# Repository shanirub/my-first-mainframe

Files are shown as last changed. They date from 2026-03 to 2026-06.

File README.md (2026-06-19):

# 🖥️ Low-Level Mainframe Simulation Using MCUs

> Simulating a banking mainframe architecture using four ESP32-C3 microcontrollers and a
> Raspberry Pi 3B+ — because understanding distributed systems is way more fun when you
> can hold the hardware in your hands.

---

## 🪦 Project status: RETIRED — frozen at ADR-012 (2026-06-18)

**This repository is closed.** The shared-I2C-bus architecture it was built around
(ADR-008 → ADR-011) has been retired *in full* by the terminal decision record
[ADR-012](docs/decisions/ADR-012-retire-shared-bus-begin-mainframe-core-redesign.md).
Work continues in a **successor project** with a different inter-device transport and a
re-centred architecture (see [Why it was retired](#-why-it-was-retired) and
[The successor](#-the-successor) below).

Nothing here is deleted. The firmware, the libraries, and the BSC slave code are preserved
as the **investigation record** — the reasoning that led to the redesign is the point of
keeping them.

| | |
|---|---|
| **Terminal ADR** | ADR-012 — *Retire the shared-bus subsystem architecture; begin mainframe-core redesign* |
| **Retired** | The shared I2C inter-device bus, the "co-equal subsystems on one bus" premise, the RPi BSC slave |
| **Still in use** | I2C for the *private* per-device OLED displays only |
| **Carried forward** | Subsystem decomposition, message semantics, FreeRTOS task pattern, SQLite/WAL durability plan, all physical hardware |

---

## 📖 What this project was

A low-level simulation of a banking mainframe built from four ESP32-C3 microcontrollers and
a Raspberry Pi 3B+, each device mapped to a distinct mainframe subsystem. The devices
communicated over a **shared I2C bus** — a single two-wire bus (SDA/SCL) shared by all
devices — chosen to mirror the channel-subsystem architecture of IBM z/OS mainframes.

Each subsystem ran autonomously and coordinated with its peers to process banking
transactions (deposits, withdrawals, transfers, balance queries). The build was
deliberately low-level: no frameworks or abstractions beyond what the project built itself,
with every design decision documented in the devlog and the ADRs (Architecture Decision
Records — short documents that capture *what* was decided and *why*).

The project was educational in intent but rigorous in execution. Real hardware constraints
were discovered through testing and resolved through principled architectural decisions —
and ultimately one of those decisions was to **stop**, which is what ADR-012 records.

---

## 🧭 Why it was retired

The retirement was an *architectural* decision, not a workaround. The recurring failures
were diagnosed as a **wrong-bus-for-the-role mismatch**, and the correct response was judged
to be changing the architecture that forced those roles — not patching the wire beneath it
again.

### The structural mismatch

I2C is a primary/secondary (historically "master/slave") bus: well suited to one controller
talking to simple peripherals. This project pressed it into **two roles it suits poorly**:

1. **Multi-master peer messaging with runtime mode-switching** — devices flipping between
   controller and target roles at runtime to form a heartbeat/ACK mesh. Documented as very
   difficult to stabilise.
2. **Target ("slave") mode on devices with weak target support** — the ESP32 I2C-slave
   initialisation path (watchdog resets, `TG1WDT_SYS_RESET`, inside untested IDF driver
   paths) and the Linux/BSC slave on the Raspberry Pi.

This was the **fourth manifestation of one underlying mismatch**. ADR-008 (SD card → three
board swaps), ADR-009 (UART backend), ADR-010 (switch to pure ESP-IDF), and ADR-011 (RPi as
BSC slave) were each well-reasoned escapes from the *same* trap — and each **moved** the
failure rather than removing it. Continuing to patch the transport was continuing to fight
the bus.

### The immediate trigger (Phase 3.3) — stated with calibrated confidence

The proximate cause surfaced at Phase 3.3: the **BCM2837 BSC** (Broadcom Serial Controller)
slave peripheral that `pigpio bsc_i2c()` drives has a **16-byte hardware FIFO** (a small
first-in-first-out buffer in silicon), which conflicts with the 256-byte fixed-buffer TX
protocol the design assumed.

Two distinct questions came out of investigating the `pigpio` source (`bscXfer()` in
`pigpio.c`), and they resolved differently:

- **Message size — closed.** The 16-byte FIFO is *not* a hard message-size limit. `pigpio`
  drains it in a software busy-loop into a 512-byte buffer while the transaction is active,
  so a chunking protocol is not *strictly* forced.
- **Reliability — not closed.** The servicing is **PIO** (programmed I/O — the CPU
  hand-copies each byte) with **no DMA** (no direct-memory-access engine to move bytes
  without the CPU). A message larger than 16 bytes at 400 kHz arrives intact only if the
  daemon is already servicing the FIFO *during* the transaction; the 16-byte slack overruns
  in roughly **360 µs**. Reliable reception is therefore a **timing gamble on a loaded Linux
  host**, not a guarantee.

The reliability question was judged **not worth resolving empirically**, because the
structural mismatch above made the whole transport the wrong foundation regardless of the
outcome of one timing test.

> *Note on a cross-reference:* the previous README attributed the MCU #3 / ESP32 I2C-slave
> retirement to ADR-011. ADR-012's own account maps the ESP32 slave-init watchdog issue to
> **ADR-010** and ADR-011 to the **RPi-as-BSC-slave** decision. This README follows ADR-012
> as the authoritative consolidating record; the exact inner ADR numbering can be reconciled
> against ADR-008–011 directly.

---

## 🚀 The successor

A new project replaces this one. ADR-012 deliberately does **not** elaborate the successor's
design — *it will have its own ADR-001 and design documents* — so only the committed
direction is recorded here (anything beyond this would be speculation):

- The **Raspberry Pi becomes the mainframe central complex**: the CICS-analogue
  (transaction monitor), the transaction processor, and the job scheduler run on the Pi as
  **software subsystems**, and durable storage (SQLite) is **local to the Pi**.
- The four **ESP32-C3 MCUs become channel-attached peripherals** — operator console,
  terminals, I/O channels — rather than co-equal bus subsystems.
- The **inter-device transport is reselected** from a bus suited to the role (the specific
  choice belongs to the successor's docs, not here).

---

## 📦 What carries forward

The transport was the failure; the system above it was not. These are sound and migrate to
the successor as concepts:

- The **subsystem decomposition** and the **CICS-minimal transaction flow**
  (deposit / withdraw / balance → durable storage → acknowledge).
- The **message semantics**: `HEARTBEAT`/`ACK`, `DB_READ`/`DB_WRITE`, job
  submit/dispatch/complete.
- The **FreeRTOS task pattern** on the MCUs and the **SQLite/WAL** (write-ahead logging — a
  journaling mode that lets storage survive a mid-write crash) durability plan.
- **All physical hardware**: the 4 ESP32-C3 MCUs, the RPi 3B+, the 5 OLEDs, the power
  arrangement, the breadboards, and the logic analyzer.

The functional goal is unchanged: a minimal CICS analogue with durable, reboot-surviving
storage. Only the architecture that delivers it changes.

---

## 🏛️ Architecture as built (historical record)

> Everything below documents the **retired** shared-bus design as it stood when the project
> was frozen. It is kept for reference, not as a description of current or future work.

Four ESP32-C3 microcontrollers and one Raspberry Pi 3B+, each mapped to a real mainframe
subsystem:

| MCU | Role | Mainframe Equivalent | I2C Address |
|-----|---|---|---|
| #1 | Master Console | System Console / Operator Interface | `0x08` |
| #2 | Transaction Processor | Central Processor (CP) | `0x09` |
| RPi 3B+ | Database Controller | DASD Controller | `0x0A` |
| #4 | Job Scheduler | JES (Job Entry Subsystem) | `0x0B` |
| #5 | I/O Controller | Channel Subsystem | `0x0C` |

> MCU #3 (ESP32-WROOM-32 DevKit) was retired across the ADR-008/011 line after an I2C
> slave-initialisation failure on the ESP32 platform (`i2c_new_slave_device()` triggering an
> unrecoverable watchdog reset; Espressif does not officially validate that slave driver path
> on the plain ESP32). The Raspberry Pi 3B+ replaced it directly at the same bus address.
> The entire shared-bus Database Controller role is itself now retired by ADR-012.

All devices shared a single I2C bus (400 kHz) and communicated via JSON-encoded messages
with a strict schema. Each device had its own OLED display showing real-time subsystem
state.

### Per-device bus architecture

Each ESP32-C3 MCU ran two independent I2C buses:
- **Shared bus (GPIO8/GPIO9):** inter-device communication via hardware `TwoWire(0)`.
- **Private OLED bus (GPIO3/GPIO10):** local display via U8g2 software I2C.

The ESP32-C3 has only one hardware I2C peripheral. That constraint was discovered during
development and resolved with U8g2 software I2C (bit-banged I2C in software on arbitrary
GPIO pins) — documented in ADR-002. **This OLED split is the one part of the I2C design that
survives the retirement.**

The Raspberry Pi 3B+ used a different mechanism for the same split:
- **Shared bus (GPIO18/GPIO19):** BCM2837 BSC slave peripheral — hardware-backed I2C slave,
  controlled via `pigpio bsc_i2c()`. GPIO18/19 are hardwired to this peripheral in silicon
  and cannot be reassigned. **(Retired by ADR-012 — see [Why it was retired](#-why-it-was-retired).)**
- **Private OLED (GPIO2/GPIO3):** BCM2837 BSC1 master peripheral via `luma.oled`. Separate
  hardware from the shared bus — no interference.

The RPi operated as a **pure I2C slave** on the shared bus: it never initiated a
transmission, and responses were returned via master-read (the requesting MCU stayed master
for the full exchange and clocked the response out of the RPi's TX FIFO). This is exactly
the path the 16-byte BSC FIFO undermined.

### FreeRTOS task architecture (MCUs) — *carries forward*

Each ESP32-C3 MCU ran a set of FreeRTOS tasks rather than a single Arduino `loop()`. Tasks
communicated via queues and shared resources via mutexes (mutual-exclusion locks). This was
a mid-project pivot (Phase 2.5) driven by a hardware constraint: `TwoWire` cannot switch
between master and slave mode at runtime without FreeRTOS managing the transition (ADR-007).

Each MCU ran at minimum:
- **Receiver task** (priority 3): wakes on I2C interrupt, puts messages on the inbound queue.
- **Logic task** (priority 2): drains the queue, handles messages, sends responses.
- **OLED task** (priority 1): updates the display independently at 500 ms intervals.

Subsystem-specific tasks were added per MCU role (HTTP server task on MCU #5, etc.). The task
pattern itself is sound and migrates to the successor.

### Python thread architecture (RPi)

The Raspberry Pi ran a Python service of three concurrent threads, mirroring the FreeRTOS
task + queue pattern:
- **bus_worker:** processed incoming bus messages, handled DB queries, loaded the TX FIFO.
- **oled_worker:** updated the SSD1306 display at 500 ms intervals.
- **flask thread** (planned Phase 4+): would serve transaction history over HTTP at port 5000.

See `docs/design/raspi_architecture.md` for the full (now historical) thread design.

---

## 💬 Example transaction flow (as designed)

A deposit of $100.00 into account 12345678, over the retired shared bus:

```
MCU #5  →  MCU #4    JOB_SUBMIT    { txnType: DEPOSIT, account: 12345678, amount: 10000 }
MCU #4  →  MCU #2    JOB_DISPATCH  { jobId: ..., txnType: DEPOSIT, account: 12345678, amount: 10000 }
MCU #2  →  RPi       DB_READ       { account: 12345678 }
RPi     →  MCU #2    DB_READ_RESULT { account: 12345678, balance: 50000, status: OK }
MCU #2  →  RPi       DB_WRITE      { account: 12345678, amount: 10000, newBalance: 60000 }
RPi     →  MCU #2    DB_WRITE_ACK  { account: 12345678, status: OK }
MCU #2  →  MCU #4    JOB_COMPLETE  { jobId: ..., status: SUCCESS }
MCU #4  →  MCU #5    JOB_RESULT    { jobId: ..., status: SUCCESS }
```

The RPi at address `0x0A` received `DB_READ`/`DB_WRITE` via I2C write transactions, then
returned results via I2C master-read (MCU #2 polled until the ready byte was set). All
monetary values are integer cents — `10000` = $100.00. Float arithmetic is never used for
money. **These message semantics carry forward to the successor; only the transport beneath
them changes.**

---

## 🛠️ Hardware (all carries forward)

| Component | Qty | Notes |
|---|-----|---|
| ESP32-C3 SuperMini | 4 | USB-C, 4 MB flash, built-in WiFi/BLE. MCUs #1, #2, #4, #5 |
| Raspberry Pi 3B+ | 1 | Was Database Controller (BSC slave on shared bus); becomes central complex in the successor |
| 0.96" SSD1306 OLED (I2C) | 5 | One per device, 128×64 px |
| DS1307 RTC module | 1 | Master Console (MCU #1), transaction timestamps |
| Logic analyzer 8-ch 24 MHz | 1 | I2C bus debugging with PulseView/Sigrok |
| 5 kΩ pull-up resistors | 2 | SDA and SCL on the (now retired) shared bus |
| Breadboards + jumper wires | — | T-shape layout on 30×30 cm wood base |

> ESP32-WROOM-32 DevKit (38-pin, CP2102) — retired as MCU #3 across the ADR-008/011 line, and
> stays retired under ADR-012.

---

## 🛠️ Development environment (as used)

- **OS:** Fedora Linux
- **IDE:** VS Code with the PlatformIO extension
- **MCU language:** C++ (Arduino framework on ESP-IDF)
- **RPi language:** Python 3 (pigpio, luma.oled; Flask + sqlite3 were planned for Phase 4)
- **RTOS:** FreeRTOS (bundled with the ESP32 Arduino framework)
- **Key libraries:** Wire (I2C), U8g2 (software I2C OLED), ArduinoJson, RTClib
- **Debugging:** 8-channel 24 MHz logic analyzer + PulseView/Sigrok

---

## 📁 Repository structure (frozen)

```
code/
  shared/
    config/shared_config.h       ← pins, addresses, FreeRTOS stack sizes
    libs/oled_display/           ← U8g2-based OLED wrapper (all MCUs) — OLED path survives
    libs/shared_bus/             ← INACTIVE: I2C bus abstraction (preserved as record)
    libs/shared_bus_wroom/       ← INACTIVE: WROOM mode-switching lib (preserved as record)
    libs/message_protocol/       ← JSON envelope, schema validation, constants — carries forward
  mcu1-master-console/
  mcu2-transaction-processor/
  mcu3-database-controller/      ← retired firmware, preserved for reference
  mcu4-job-scheduler/
  mcu5-io-controller/
  raspi-db-server/               ← includes bus_slave.py (INACTIVE BSC slave code, preserved)
docs/
  requirements.md                ← functional and non-functional requirements
  devlog.md                      ← chronological build log with key learnings
  design/
    system_design.md             ← architecture, data flows, data model
    message_protocol.md          ← full JSON message format specification
    freertos_architecture.md     ← FreeRTOS task design for all MCUs
    raspi_architecture.md        ← Raspberry Pi thread architecture
  decisions/                     ← ADR-001 … ADR-012 (ADR-012 is terminal)
  poc_rtos/                      ← FreeRTOS PoC plan, results, sequence diagrams
  captures/                      ← PulseView captures, OLED photos
roadmap.md                       ← phased development plan (superseded by the successor)
scripts/
  claude_memory_sync.py          ← git hook: syncs CLAUDE.md to AI assistant memory
```

---

## 🗺️ Project status (final)

| Phase | Description | Status |
|---|---|---|
| 1 | Foundation — environment, I2C basics, OLED | ✅ Complete |
| 1.5 | Hardware fix — dual I2C bus, shared libraries | ✅ Complete |
| 2 | Protocol — JSON messaging, all devices on shared bus | ✅ Complete |
| 2.5 | FreeRTOS pivot — validated multi-master I2C with tasks | ✅ Complete |
| 3 | Individual subsystems — simple implementations per device | ⛔ In progress when retired — the Phase 3.3 BSC-FIFO finding triggered ADR-012 |
| 4 | Integration — production implementations, end-to-end flow | ⏭️ Not started — carried to successor |
| 5 | Advanced features — two-phase commit, crash recovery, load testing | ⏭️ Not started — carried to successor |

**Repository frozen at ADR-012.** New work begins in the successor project.

---

## 🔑 Key engineering decisions (record)

These decisions stand as the reasoning trail. The ones marked *carries forward* migrate to
the successor; the shared-bus-specific ones are now historical.

**FreeRTOS over Arduino `loop()`** *(carries forward)* — The ESP32-C3 `TwoWire` peripheral
locks into master or slave mode at boot, so slave MCUs could not initiate transmissions
without routing everything through MCU #1. FreeRTOS tasks with a mutex-protected bus let any
MCU temporarily become master. See ADR-007.

**Software I2C for OLED** *(survives)* — The ESP32-C3 has only one hardware I2C peripheral,
so OLED and shared bus could not both be hardware buses. U8g2 software I2C on separate GPIO
pins solved it cleanly. See ADR-002.

**Raspberry Pi as Database Controller** *(retired)* — The plain ESP32 I2C slave driver caused
an unrecoverable watchdog reset on boot, so the RPi's BCM2837 BSC slave peripheral was
adopted as a hardware-backed, better-supported alternative. This is the path ADR-012 retires:
the BSC slave's 16-byte FIFO made reliable reception a timing gamble. See ADR-010, ADR-011,
and the terminal ADR-012.

**Integer cents for money** *(carries forward)* — All monetary values are stored and
transmitted as `uint32_t` cents (`10000` = $100.00). Float arithmetic is never used for money
— a standard rule in financial software. See ADR-005.

**Strict JSON schema validation** *(carries forward)* — Every received message was validated
against a schema registry before processing; missing fields were rejected with a typed error
code. This caught several bugs that would otherwise have caused silent incorrect behaviour.

---

## 📚 Learning resources

- [IBM Redbooks — Introduction to the New Mainframe: z/OS Basics](https://www.redbooks.ibm.com/)
- [FreeRTOS Documentation](https://www.freertos.org/Documentation/RTOS_book.html)
- [ArduinoJson Documentation](https://arduinojson.org/)
- [U8g2 Library](https://github.com/olikraus/u8g2)
- [PulseView / Sigrok — I2C Decoder Guide](https://sigrok.org/wiki/Protocol_decoder:I2c)
- [pigpio library — bsc_i2c](https://abyz.me.uk/rpi/pigpio/python.html#bsc_i2c)

---

## 📝 License

This project is open source and available under the [MIT License](LICENSE).

---

*Built with curiosity, a soldering iron, and an unhealthy interest in how mainframes actually
work — and retired, on purpose, the moment the architecture (not the effort) stopped being
right.*

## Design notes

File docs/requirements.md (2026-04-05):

# Requirements — Low-Level Mainframe Simulation

## Functional Requirements

| ID | Requirement | Phase |
|----|---|---|
| FR-01 | System shall accept banking commands via MCU #1 serial console | 3 |
| FR-02 | System shall process DEPOSIT and WITHDRAW transactions | 4 |
| FR-03 | System shall persist account balances across power cycles (SD card) | 3 |
| FR-04 | System shall maintain a transaction log separate from account data | 3 |
| FR-05 | System shall recover incomplete transactions after power loss (crash recovery) | 5 |
| FR-06 | System shall prioritise jobs as HIGH / MEDIUM / LOW | 4 |
| FR-07 | System shall detect and report subsystem failures via HEARTBEAT | 4 |
| FR-08 | System shall display real-time subsystem state on each OLED | 3 |
| FR-09 | System shall reject transactions with insufficient funds | 4 |
| FR-10 | System shall support atomic TRANSFER between accounts (two-phase commit) | 5 |
| FR-11 | MCU #5 shall host a web console for submitting transactions and checking balances | 3 |
| FR-12 | System shall support BALANCE enquiry — read account balance without modifying it | 3 |

## Non-Functional Requirements

| ID | Requirement | Phase |
|----|---|---|
| NFR-01 | Transaction end-to-end latency shall be under 500ms under normal load | 4 |
| NFR-02 | Job queue shall accept and process 50 sequential transactions without dropping any | 5 |
| NFR-03 | I2C messages shall not exceed 256 bytes (expanded buffer via build flag) | 2 |
| NFR-04 | Each MCU shall respond to HEARTBEAT within 1 second | 4 |
| NFR-05 | System shall operate on 5V USB power, total draw under 1A per MCU | 1 |
| NFR-06 | All inter-MCU messages shall be human-readable JSON in Phases 1–4 | 2 |

## Out of Scope (current version)

- RFID card reader integration
- Binary message protocol optimisation (Phase 5 candidate)
- Message encryption
- Web dashboard (MCU #1 WiFi)
- Real network connectivity

## Definition of Done — per requirement

A requirement is done when:
1. A test scenario exists that exercises it
2. The test passes on real hardware
3. Pass/fail result is documented in devlog.md
4. No regressions in previously passing requirements

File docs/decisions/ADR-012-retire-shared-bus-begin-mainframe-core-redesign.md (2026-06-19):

# ADR-012: Retire the shared-bus subsystem architecture; begin mainframe-core redesign

## Status
Accepted — 2026-06-18
Terminal ADR for this project. The shared-bus architecture (ADR-008 through
ADR-011) is retired in full. Work continues in a successor project (see
"Successor" below).

## Supersedes
ADR-011 (RPi as I2C slave on the shared bus). Closes the ADR-008 → ADR-011 line.

---

## Context

The Database Controller subsystem was never reliably realized on the shared I2C
bus. The immediate trigger was a hardware constraint found at Phase 3.3: the
BCM2837 BSC (Broadcom Serial Controller) slave peripheral that `pigpio
bsc_i2c()` drives has a 16-byte hardware FIFO (RX and TX), which conflicts with
the 256-byte fixed-buffer TX protocol the design assumed.

Investigation of the `pigpio` source (`bscXfer()` in `pigpio.c`) established
that the 16-byte FIFO is *not* a hard message-size limit — pigpio drains it in a
software busy-loop into a 512-byte buffer while the bus transaction is active.
But the servicing is PIO (programmed I/O — the CPU hand-copies each byte) with
no DMA: a message larger than 16 bytes at 400 kHz is received intact only if the
daemon is already servicing the FIFO *during* the transaction, and the 16-byte
slack overruns in roughly 360 µs. Reliable reception is therefore a timing
gamble on a loaded Linux host, not a guarantee.

*Calibration: the size question is closed (pigpio accumulates, so a chunking
protocol is not strictly forced); the reliability question is not closed, and
was judged not worth resolving empirically given everything below.*

More important than the trigger is the pattern behind it. This was the **fourth
manifestation of one structural mismatch**: I2C used for two roles it is poorly
suited to —

1. multi-master peer messaging with runtime master↔slave mode-switching (the
   heartbeat/ACK mesh, documented as very difficult to stabilize), and
2. slave mode on devices with weak slave support — ESP32 I2C slave
   initialization (ADR-010: `TG1WDT_SYS_RESET` watchdog resets inside untested
   IDF driver paths) and the Linux/BSC slave (this ADR).

ADR-008 (SD card → three board swaps), ADR-009 (UART backend), ADR-010
(framework switch to pure ESP-IDF), and ADR-011 (RPi as BSC slave) were each
well-reasoned escapes from this same trap. Each moved the failure rather than
removing it. Continuing to patch the transport is continuing to fight the bus.

---

## Decision

**End this project.** The shared-bus-of-co-equal-subsystems premise is retired
in full — not patched, not re-transported. No further ADRs extend the
ADR-008–011 line.

The decision is deliberate and architectural, not a workaround. The recurring
failures are diagnosed as a wrong-bus-for-the-role mismatch; the correct
response is to change the architecture that forces those roles, not the wire
beneath it.

---

## Successor

A new project replaces this one. In it, the **Raspberry Pi becomes the mainframe
central complex**: the CICS-analogue, the transaction processor, and the job
scheduler run on the Pi as software subsystems, and durable storage (SQLite) is
local to the Pi. The four ESP32-C3 MCUs become **channel-attached peripherals**
(operator console, terminals, I/O channels) rather than co-equal bus subsystems.
The inter-device transport is reselected from a bus suited to the role.

The successor's design is intentionally **not** elaborated here. It will have its
own ADR-001 and design documents.

---

## What carries forward

The transport was the failure; the system above it was not. These are sound and
migrate to the successor as concepts:

- The subsystem decomposition and the CICS-minimal transaction flow
  (deposit / withdraw / balance → durable storage → acknowledge).
- The message semantics (HEARTBEAT/ACK, DB_READ/DB_WRITE, job
  submit/dispatch/complete).
- The FreeRTOS task pattern on the MCUs and the SQLite/WAL durability plan.
- All physical hardware: the 4 ESP32-C3 MCUs, the RPi 3B+, the 5 OLEDs, the
  power arrangement, the breadboards, and the logic analyzer.

---

## Consequences

- The shared I2C inter-device bus (hub, 5 kΩ pull-ups) and the Pi BSC slave
  (GPIO18/19) are retired. I2C remains in use only for the private OLED
  displays.
- The ESP32-WROOM-32 (already retired, ADR-008/011) stays retired. The
  `shared_bus` / `shared_bus_wroom` mode-switching libraries and the
  `bus_slave.py` BSC code are inactive — preserved in the repo as the
  investigation record, not deleted.
- This repo is frozen at this ADR. New work begins in the successor project.
- No functional requirement changes. The goal — a minimal CICS analogue with
  durable, reboot-surviving storage — is unchanged. Only the architecture that
  delivers it changes.

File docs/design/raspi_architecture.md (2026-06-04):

# Raspberry Pi Architecture — Database Controller (0x0A)

## Overview

The Raspberry Pi 3B+ replaces MCU #3 as the Database Controller on the
shared inter-MCU I2C bus. It runs a Python service structured as three
concurrent threads, mirroring the FreeRTOS task + queue pattern used on
the MCUs. See ADR-011 for the full reasoning behind this architecture.

Unlike the MCUs, the RPi runs a standard Linux OS (Raspberry Pi OS Lite).
Concurrency is provided by Python's `threading` module (preemptive, OS-
scheduled) rather than FreeRTOS (cooperative, RTOS-scheduled). The mental
model is intentionally the same: threads are tasks, `queue.Queue` is the
inter-thread queue, `threading.Lock` is the mutex.

---

## Hardware

| Bus | Peripheral | GPIO | Role |
|-----|---|---|---|
| Shared inter-MCU I2C | BCM2837 BSC slave | GPIO18 (SDA), GPIO19 (SCL) | Receive DB_READ, DB_WRITE, HEARTBEAT from bus |
| Private OLED | BCM2837 BSC1 master | GPIO2 (SDA), GPIO3 (SCL) | Drive SSD1306 display |

GPIO18/19 and GPIO2/3 are separate hardware peripherals on the BCM2837.
They do not interfere with each other and connect to separate physical wires.
Only GPIO18/19 connects to the shared bus hub.

---

## Thread Architecture

```
┌─────────────────────────────────────────────────────────────────┐
│                     pigpio daemon (C thread)                    │
│              runs outside the Python process                    │
└──────────────────────────┬──────────────────────────────────────┘
                           │ EVENT_BSC fires on bus activity
                           │ on_bsc_event() callback:
                           │   read RX FIFO via bsc_i2c()
                           │   bus_queue.put(raw_bytes)   ← non-blocking
                           ▼
                  ┌─────────────────┐
                  │   bus_queue     │  queue.Queue(maxsize=8)
                  │                 │  each slot: raw bytes from BSC RX FIFO
                  └────────┬────────┘
                           │
                           ▼
┌──────────────────────────────────────────────────────────────────┐
│  bus_worker thread                                               │
│                                                                  │
│  while True:                                                     │
│    raw = bus_queue.get()          # blocks — no CPU consumed     │
│    request = parse_json(raw)                                     │
│    response = handle(request)     # DB query (Phase 4+)         │
│                                   # or stub response (Phase 3)  │
│    load_tx_fifo(response)         # bsc_i2c(ADDR, payload)      │
│    with display_lock:                                            │
│      display_state.update(request, response)                    │
└──────────────────────────────────────────────────────────────────┘

┌──────────────────────────────────────────────────────────────────┐
│  oled_worker thread                                              │
│                                                                  │
│  while True:                                                     │
│    with display_lock:                                            │
│      snap = copy(display_state)                                  │
│    oled.show(snap)                # luma.oled SSD1306 driver    │
│    time.sleep(0.5)                                               │
└──────────────────────────────────────────────────────────────────┘

┌──────────────────────────────────────────────────────────────────┐
│  flask thread  (Phase 4+)                                        │
│                                                                  │
│  app.run(host='0.0.0.0', port=5000)                              │
│  reads SQLite directly — WAL mode allows concurrent reads        │
└──────────────────────────────────────────────────────────────────┘
```

---

## Thread Summary

| Thread | Priority | Equivalent FreeRTOS task | Phase |
|---|---|---|---|
| bus_worker | High (OS default) | Logic task (pri=2) | 3 |
| oled_worker | Low (OS default) | OLED task (pri=1) | 3 |
| flask | Low (OS default) | HTTP server task | 4 |

Python threads are preemptively scheduled by the OS. Unlike FreeRTOS,
there is no explicit numeric priority assignment — the OS scheduler
manages time-slicing. The `bus_worker` thread naturally gets priority
because it blocks on `queue.Queue.get()` and only runs when work arrives,
while `oled_worker` sleeps 500ms between iterations.

---

## Shared State

```python
# Protected by display_lock — same pattern as FreeRTOS displayMutex.
# Written by bus_worker, read by oled_worker and Flask.

display_lock = threading.Lock()

display_state = {
    "status":       "IDLE",      # "IDLE" | "DB_READ" | "DB_WRITE" | "HEARTBEAT"
    "last_account": "",          # 8-digit account string, empty if none yet
    "last_result":  "",          # "OK" | "NOT_FOUND" | "TIMEOUT" | "ERROR"
}
```

`display_lock` is held for the minimum time needed to read or write
`display_state` — never while doing I/O (SQLite, OLED, I2C).

---

## TX FIFO Protocol

The MCU always reads exactly 256 bytes from the RPi. Byte 0 is the ready
flag; bytes 1–255 carry the JSON response payload (padded with null bytes).

```python
READY     = b'\x01'
NOT_READY = b'\x00'

def load_tx_fifo(response_json: str):
    payload = response_json.encode('utf-8')
    # Truncate if over 255 bytes — should not happen given message sizes
    buf = READY + payload[:255]
    buf = buf.ljust(256, b'\x00')   # pad to exactly 256 bytes
    pi.bsc_i2c(I2C_ADDR, buf)       # loads TX FIFO, sets ready_byte = 0x01

def clear_tx_fifo():
    pi.bsc_i2c(I2C_ADDR, NOT_READY + b'\x00' * 255)
```

`clear_tx_fifo()` is called at startup and after each response is delivered,
ensuring the ready flag is 0x00 between transactions. This prevents the MCU
from reading a stale response from a previous transaction.

---

## Message Handling

The `bus_worker` handles all message types. Logic is sequential — one
request processed at a time, matching the MCU #2 Phase 3 sequential model.

```python
def handle(request: dict) -> str:
    op = request.get("tp")   # message type — matches MsgType constants

    if op == MsgType.HEARTBEAT:
        return build_heartbeat_ack()

    elif op == MsgType.DB_READ:
        account = request["p"]["ac"]
        # Phase 3: return stub response
        # Phase 4+: return db.read(account)
        return build_db_read_result(account, balance=50000, status=Status.OK)

    elif op == MsgType.DB_WRITE:
        account  = request["p"]["ac"]
        new_bal  = request["p"]["nb"]
        txn_type = request["p"]["tt"]
        msg_id   = request["mid"]
        # Phase 3: return stub ACK
        # Phase 4+: return db.write(account, new_bal, txn_type, msg_id)
        return build_db_write_ack(account, status=Status.OK)

    else:
        return build_error(f"unknown type: {op}")
```

Phase 3 stubs return hardcoded values. Phase 4 replaces the stub calls with
`db.read()` and `db.write()` from `db.py` — the thread structure and
protocol do not change.

---

## SQLite Strategy (Phase 4+)

SQLite is accessed exclusively from `bus_worker`. Flask reads the database
directly in its own thread.

Concurrency model:
- `bus_worker` is the sole writer. No write contention possible.
- Flask is a reader only. WAL mode (Write-Ahead Log) allows concurrent
  reads while `bus_worker` is writing — no blocking between threads.
- One SQLite connection per thread (`check_same_thread=True`, default).
  `bus_worker` holds its own connection; Flask holds its own.

```python
# bus_worker connection (opened once at thread start)
conn = sqlite3.connect("mainframe.db", check_same_thread=True)
conn.execute("PRAGMA journal_mode=WAL")
conn.execute("PRAGMA foreign_keys=ON")
```

Write-ahead log pattern for DB_WRITE (atomic — single SQLite transaction):
1. Insert transaction row with `status='PENDING'`
2. Update account balance
3. Update transaction row to `status='COMMITTED'`

On RPi boot, any `PENDING` rows that never reached `COMMITTED` indicate an
interrupted write. Phase 5 adds replay logic for these rows.

---

## OLED Display

Driver: `luma.oled` with SSD1306 on I2C bus 1 (GPIO2/3, `/dev/i2c-1`).

```
DATABASE CTRL
Addr: 0x0A
DB READ / IDLE
Acct: 12345678
```

Line 3 reflects `display_state["status"]` — updates on every bus event.
Line 4 shows `display_state["last_account"]` — blank until first request.

`oled_worker` reads a snapshot of `display_state` under `display_lock`,
then renders outside the lock. The lock is held for microseconds; the
luma.oled I2C write takes ~5ms and is never inside the lock.

---

## Startup Sequence

```
main():
  1. init pigpio daemon connection
  2. arm BSC slave: pi.bsc_i2c(I2C_ADDR)
  3. clear TX FIFO: load NOT_READY + zeros
  4. register EVENT_BSC callback: on_bsc_event
  5. init luma.oled on /dev/i2c-1
  6. display "BOOT OK" on OLED
  7. start bus_worker thread (daemon=True)
  8. start oled_worker thread (daemon=True)
  9. [Phase 4+] start flask thread (daemon=True)
 10. main thread blocks: signal.pause()  ← keeps process alive
```

`daemon=True` on all threads: if the main thread exits (e.g. KeyboardInterrupt),
all threads are cleaned up automatically. No explicit join needed for normal
shutdown.

---

## File Structure

```
code/raspi-db-server/
  CLAUDE.md           — setup steps, design notes, DoD per phase
  src/
    main.py           — startup sequence, thread creation
    bus_slave.py      — pigpio bsc_i2c setup, EVENT_BSC callback, TX FIFO protocol
    db.py             — SQLite read/write, WAL mode (Phase 4+)
    web_server.py     — Flask transaction history at :5000 (Phase 4+)
    oled.py           — luma.oled SSD1306 driver, oled_worker thread
    protocol.py       — message type constants, JSON builders (mirrors MessageProtocol)
  schema/
    schema.sql        — accounts + transactions tables (Phase 4+)
```

---

## Correspondence to FreeRTOS Pattern

| FreeRTOS (MCU) | Python (RPi) |
|---|---|
| `xTaskCreate(busWorker, pri=3)` | `threading.Thread(target=bus_worker)` |
| `xTaskCreate(oledTask, pri=1)` | `threading.Thread(target=oled_worker)` |
| `xQueueCreate(8, 256)` | `queue.Queue(maxsize=8)` |
| `xQueueReceive(q, portMAX_DELAY)` | `bus_queue.get()` — blocks, no CPU |
| `xQueueSend(q, item, 0)` | `bus_queue.put_nowait(item)` |
| `xSemaphoreTake(displayMutex)` | `with display_lock:` |
| `xSemaphoreGive(displayMutex)` | *(automatic on `with` block exit)* |
| `vTaskDelay(pdMS_TO_TICKS(500))` | `time.sleep(0.5)` |
| ISR callback → semaphore | pigpio EVENT_BSC callback → `queue.put()` |

The key structural difference: the pigpio callback fires from the pigpio
daemon's internal C thread — outside the Python process's thread model
entirely. `queue.Queue` is thread-safe and is the correct handoff mechanism
between the callback and `bus_worker`.

---

## Known Constraints

**pigpio daemon required:** `pigpiod` must be running before the Python
service starts. Add to `/etc/rc.local` or use a systemd service.

**BSC slave TX FIFO one-shot:** Once the MCU reads the TX FIFO, the BSC
slave hardware clears it. The ready flag drops to 0x00 naturally after
the read. `clear_tx_fifo()` is called defensively at startup and between
transactions.

**No clock stretching control:** The MCU drives SCL and will clock out
whatever is in the TX FIFO immediately. The ready-flag polling loop on the
MCU side is the only mechanism that handles RPi processing latency.

**Single SQLite writer:** All writes go through `bus_worker`. This is
intentional — it eliminates write contention and matches the Phase 3
sequential transaction model. Phase 5 concurrency (if needed) would
require a dedicated DB task and a request queue, matching the MCU #3
`sdQueue` / `sdResultQueue` pattern from the original FreeRTOS design.

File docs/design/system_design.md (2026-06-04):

# System Design — Low-Level Mainframe Simulation

## 1. Overview

A simulation of a banking mainframe architecture using four ESP32-C3 microcontrollers and
a Raspberry Pi 3B+, each representing a distinct mainframe subsystem. The devices
communicate over a shared I2C bus, mirroring IBM z/OS channel subsystem architecture.
The system processes banking transactions — deposits, withdrawals, and transfers —
providing hands-on experience with distributed system design, job scheduling, persistent
storage, and failure handling.

## 2. Requirements

See docs/requirements.md.

## 3. Architecture

### Subsystem Map

| Device | Role | Mainframe Equivalent | I2C Address |
|---|---|---|---|
| MCU #1 | Master Console | System Console / Operator Interface | 0x08 |
| MCU #2 | Transaction Processor | Central Processor (CP) | 0x09 |
| RPi 3B+ | Database Controller | DASD Controller | 0x0A |
| MCU #4 | Job Scheduler | JES (Job Entry Subsystem) | 0x0B |
| MCU #5 | I/O Controller | Channel Subsystem | 0x0C |

> MCU #3 (ESP32-WROOM-32 DevKit) — retired. See ADR-011.

### Communication Topology

All devices share one I2C bus (400kHz Fast Mode) via a central hub breadboard.
ESP32-C3 MCUs are multi-master capable — any MCU can initiate a transmission. Pull-up
resistors (5kΩ) on SDA and SCL lines. All devices share a common GND reference.

The Raspberry Pi 3B+ participates as a **pure I2C slave**. It connects to the shared bus
hub via GPIO18/19 (BCM2837 BSC slave peripheral — hardware-backed, not bit-banging).
The RPi never generates a START condition on the bus. Responses are returned via
master-read: the requesting MCU remains bus master and clocks the response out of the
RPi's TX FIFO. This is a different participation model from the MCUs but is transparent
to the rest of the bus — address 0x0A behaves identically from the caller's perspective.

### Per-Device Bus Architecture

Each ESP32-C3 MCU runs two independent I2C buses:
- Hardware I2C (TwoWire(0)): GPIO8=SDA, GPIO9=SCL — shared inter-device bus
- Software I2C (U8g2): GPIO3=SDA, GPIO10=SCL — private OLED display

The Raspberry Pi 3B+ uses two separate hardware peripherals on the BCM2837 SoC
(System-on-Chip):
- BSC slave (pigpio bsc_i2c): GPIO18=SDA, GPIO19=SCL — shared inter-device bus
- BSC1 master (luma.oled): GPIO2=SDA, GPIO3=SCL — private OLED display

GPIO18/19 and GPIO2/3 are separate peripherals in silicon. They do not interfere with
each other and connect to separate physical wires. Only GPIO18/19 connects to the shared
bus hub.

### Physical Layout

T-shape arrangement on 30×30cm wood base:
- Vertical long BB (spine): RPi 3B+ + hub
- Horizontal long BB (base): MCU #4 + MCU #5
- Short BB left: MCU #1
- Short BB right: MCU #2

## 4. Data Flow

### Deposit Transaction

```
MCU #5 (I/O) → MCU #4 (Scheduler):   JOB_SUBMIT
MCU #4 → MCU #2 (Processor):         JOB_DISPATCH
MCU #2 → RPi (Database, 0x0A):       DB_READ  (I2C write transaction)
RPi processes request, loads response into TX FIFO
MCU #2 → RPi:                         master-read (polls ready byte, 256 bytes)
RPi → MCU #2:                         DB_READ_RESULT  (via TX FIFO)
MCU #2 → RPi:                         DB_WRITE  (I2C write transaction)
RPi processes write, updates SQLite, loads ACK into TX FIFO
MCU #2 → RPi:                         master-read (polls ready byte, 256 bytes)
RPi → MCU #2:                         DB_WRITE_ACK  (via TX FIFO)
MCU #2 → MCU #4:                      JOB_COMPLETE
MCU #4 → MCU #5:                      JOB_RESULT
MCU #1 logs all messages throughout
```

Note: DB_READ_RESULT and DB_WRITE_ACK are not pushed by the RPi. They are returned via
master-read — MCU #2 polls `requestFrom(0x0A, 256)` in a loop until byte[0] (the ready
flag) is `0x01`, or a 500ms timeout elapses. This uses the `sendAndReceive()` method
added to the SharedBus library (Phase 3). See ADR-011 for the full protocol.

### Heartbeat

```
MCU #1 → all slaves (broadcast):   HEARTBEAT
Each MCU → MCU #1:                 HEARTBEAT_ACK  (pushed response, existing pattern)
RPi → MCU #1:                      HEARTBEAT_ACK  (via master-read, 20ms fixed delay)
MCU #1: updates OLED with active subsystem count
MCU #1: flags any device that does not respond within timeout
```

HEARTBEAT to the RPi uses `sendAndReceive()` with a fixed 20ms delay before the single
read (no poll loop needed — HEARTBEAT_ACK requires no SQLite query).

### Balance Enquiry

```
MCU #5 (I/O) → MCU #4 (Scheduler):  JOB_SUBMIT (txnType: BALANCE)
MCU #4 → MCU #2 (Processor):        JOB_DISPATCH
MCU #2 → RPi:                        DB_READ  + master-read
RPi → MCU #2:                        DB_READ_RESULT (balance)
MCU #2 → MCU #4:                     JOB_COMPLETE (balance in result)
MCU #4 → MCU #5:                     JOB_RESULT (balance)
MCU #5: displays balance on OLED / web console
```
Note: BALANCE is read-only — no DB_WRITE step.

### Insufficient Funds

```
MCU #2 → RPi: DB_READ  + master-read
RPi → MCU #2: DB_READ_RESULT (balance < amount)
MCU #2 → MCU #4: JOB_COMPLETE (status: FAILED, reason: INSUFFICIENT_FUNDS)
MCU #4 → MCU #5: JOB_RESULT (failed)
```

## 5. Data Model

### RPi — SQLite Storage (Phase 4+)

The RPi stores all account data in a SQLite database (`mainframe.db`) on its own SD card.
SQLite operates in WAL mode (Write-Ahead Log — allows concurrent reads while a write is
in progress) so Flask can read while `bus_worker` is writing, without blocking.

**Note on money representation:** All monetary values are stored and transmitted as integer
cents (uint32_t). $100.00 = 10000. Float arithmetic is never used for money — see ADR-005.
Formatting for display ($100.00) is done at output time only.

**accounts table**
```sql
CREATE TABLE accounts (
    account_id TEXT PRIMARY KEY,   -- 8-digit string e.g. "12345678"
    balance    INTEGER NOT NULL    -- cents, never float
);
```

**transactions table**
```sql
CREATE TABLE transactions (
    id         TEXT PRIMARY KEY,   -- UUID v4 from MCU message mid field
    account_id TEXT NOT NULL,
    txn_type   INTEGER NOT NULL,   -- matches TxnType constants: 1=DEPOSIT 2=WITHDRAW 4=BALANCE
    amount     INTEGER NOT NULL,   -- cents
    new_bal    INTEGER NOT NULL,   -- balance after transaction
    status     TEXT NOT NULL,      -- 'PENDING' or 'COMMITTED'
    ts         DATETIME DEFAULT CURRENT_TIMESTAMP
);
```

Write-ahead log pattern for DB_WRITE (all three steps in a single SQLite transaction —
atomic):
1. Insert transaction row with `status='PENDING'`
2. Update account balance
3. Update transaction row to `status='COMMITTED'`

On RPi boot, any `PENDING` rows that never reached `COMMITTED` indicate an interrupted
write. Phase 5 adds replay logic for these rows.

**Phase 3 note:** SQLite is deferred to Phase 4. In Phase 3, `bus_worker` returns
hardcoded stub responses for DB_READ and DB_WRITE. The protocol, thread structure, and TX
FIFO mechanism are all live in Phase 3 — only the database backend is stubbed.

**Account seeding:** The accounts table is pre-populated before first use. Runtime account
creation via MCU #1 serial console is a Phase 3 feature.

### MCU #4 — Job Queue (in memory)

```cpp
struct Job {
    uint16_t jobId;       // composite: (senderAddr << 8) | sequenceNum
    uint8_t  priority;    // 0=HIGH, 1=MEDIUM, 2=LOW
    uint8_t  status;      // QUEUED, DISPATCHED, COMPLETE, FAILED
    char     type[16];    // "DEPOSIT", "WITHDRAW", "TRANSFER", "BALANCE"
    char     account[9];  // 8-digit account number + null terminator
    uint32_t amount;      // cents — never float
    uint32_t submittedAt;
    uint32_t dispatchedAt;
};
```

## 6. Interface Definitions

See docs/design/message_protocol.md.

## 7. Error Handling

### Subsystem Failure
- MCU #1 sends HEARTBEAT periodically to all devices including RPi
- Any device not responding within timeout is flagged on OLED
- Pending jobs for a failed subsystem are marked FAILED after timeout

### Message Timeout
- Sender waits max 500ms for response
- On timeout: logs error to MCU #1, returns BusError::TIMEOUT
- For RPi interactions: `sendAndReceive()` returns Status::TIMEOUT after 500ms poll
- MCU #4 retries dispatched jobs once before marking FAILED

### Malformed Message
- Receiver fails to parse JSON → logs error, discards message
- No retry — sender must detect via timeout

### Insufficient Funds
- MCU #2 detects during DB_READ_RESULT processing
- Returns JOB_COMPLETE with status FAILED and reason field
- No retry — this is a business logic rejection, not a system error

## 8. Open Questions

- [ ] RTC timestamp source for transaction log — DS1307 on MCU #1?
- [ ] How should MCU #1 web dashboard be structured (Phase 4)?
- [ ] Should MCU #4 persist the job queue to survive power loss?
- [ ] Maximum queue depth for MCU #4 before rejecting new jobs?
- [ ] Two-phase commit protocol design for TRANSFER (Phase 5)
- [ ] MCU #5 web console design — HTML form for DEPOSIT/WITHDRAW/BALANCE/TRANSFER
- [ ] WiFi + I2C simultaneous operation stability on ESP32-C3 (risk: timing interference)
- [ ] Runtime account creation via MCU #1 serial console (Phase 3 feature)
- [ ] Account administration — who can create/delete accounts, balance limits?
- [ ] BSC slave TX FIFO behaviour under rapid sequential requests — needs validation on
      real hardware in Phase 3 (clear_tx_fifo() between transactions assumed sufficient)

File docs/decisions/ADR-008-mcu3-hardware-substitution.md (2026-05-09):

# ADR-008: WeMos LOLIN32 Lite replaces ESP32-C3 SuperMini for MCU #3

## Status
~~Accepted — 2026-04-16, amended 2026-04-18~~
**Superseded by ADR-009 — 2026-05-07**
SD card storage approach abandoned. MCU #3 retained on shared bus; storage
delegated to Raspberry Pi 3B+ over UART. See ADR-009 for full reasoning.

---

## Reference Documents

**ESP32-C3 (replaced board):**
- ESP32-C3 Series Datasheet: https://www.espressif.com/sites/default/files/documentation/esp32-c3_datasheet_en.pdf
- ESP32-C3 Technical Reference Manual: https://www.espressif.com/sites/default/files/documentation/esp32-c3_technical_reference_manual_en.pdf
- ESP32-C3-MINI-1 Module Datasheet: https://documentation.espressif.com/esp32-c3-mini-1_datasheet_en.pdf

**WeMos LOLIN32 Lite (replacement board):**
- ESP32 Series Datasheet (covers ESP32-D0WDQ6): https://www.espressif.com/sites/default/files/documentation/esp32_datasheet_en.pdf
- ESP32 Technical Reference Manual: https://www.espressif.com/sites/default/files/documentation/esp32_technical_reference_manual_en.pdf
- WeMos LOLIN32 Lite pinout and specs (Mischianti): https://mischianti.org/esp32-wemos-lolin32-lite-high-resolution-pinout-and-specs/

---

## Context

MCU #3 (Database Controller) requires four peripherals to run simultaneously:

| Peripheral | Pins needed |
|---|---|
| Shared inter-MCU I2C bus | GPIO8=SDA, GPIO9=SCL |
| Private OLED display (U8g2 SW_I2C) | 2 GPIOs |
| SPI SD card (MOSI, MISO, SCK, CS) | 4 GPIOs |

The ESP32-C3 SuperMini exposes 11 GPIO pins total. Per the ESP32-C3 Series
Datasheet and Technical Reference Manual, the following pins are unavailable
for general user SPI:

| GPIO | Reason unavailable |
|---|---|
| GPIO6 | FSPICLK — flash SPI clock, used in all flash modes |
| GPIO7 | FSPID — flash SPI data, used in Dual I/O and Quad I/O flash modes |
| GPIO11 | FSPICS0 — flash SPI chip select |
| GPIO12–17 | SPI0/SPI1 — internal flash interface, not broken out on SuperMini |
| GPIO4–7 | Shared with JTAG interface (per TRM Chapter IO MUX) |
| GPIO0 | Strapping pin — boot mode selection |
| GPIO2 | Strapping pin — avoid pulling low at boot |
| GPIO8 | Strapping pin + onboard LED (already in use: shared bus SDA) |
| GPIO9 | BOOT button (already in use: shared bus SCL) |

After subtracting the shared bus (GPIO8/9) and OLED (GPIO3/10), the
nominally remaining pins are GPIO0, GPIO1, GPIO2, GPIO5, GPIO20, GPIO21.
However, GPIO0 and GPIO2 are strapping pins with boot-mode sensitivity,
leaving GPIO1, GPIO5, GPIO20, GPIO21 as the only clean candidates —
exactly 4 pins for 4 SPI signals, with zero margin.

In practice, extensive testing confirmed the chip does not behave reliably
with user SPI on these pins in combination:

- **GPIO6/7 combination (first attempt):** confirmed dead — internal flash
  pins show 0V externally regardless of firmware configuration
- **GPIO5/20 combination:** SdFat error 0x17 (CMD0 — card never responded),
  crashes in `spiTransferByteNL` and `cpu_ll_waiti`
- **GPIO0/1 combination:** same CMD0 failure; additionally GPIO0 affected
  boot mode (boot:0xe vs expected boot:0xf)

A SPI loopback test (MOSI jumpered to MISO) passed on all combinations,
confirming the SPI2 peripheral hardware itself is functional. The failure
is specific to the SD card communication path — most likely due to
interactions between the GPIO matrix, JTAG peripheral, and flash controller
that only manifest under active SPI bus traffic.

The ESP32-C3 Technical Reference Manual notes that SPI2 pins are multiplexed
with GPIO2, GPIO4–GPIO7, GPIO10, and the JTAG interface via the IO MUX
(TRM Section "SPI Controller"). Even pins not used for flash at runtime may
have residual contention from the IO MUX configuration established at boot.

**Conclusion:** The ESP32-C3 SuperMini does not have sufficient reliably-usable
GPIOs to run shared I2C bus + OLED + SPI SD card simultaneously in practice,
even though a naive pin count suggests it should be possible. This is a
silicon-level constraint exposed through testing, not a firmware issue.

---

## Decision

Replace the ESP32-C3 SuperMini with a **WeMos LOLIN32 Lite** (or compatible
clone — the original is discontinued) for MCU #3 only. The board in use is
a clone based on the ESP32-D0WDQ6 chip with CH340C USB-to-serial, PCB
antenna, single RST button, and JST LiPo connector. All other MCUs remain
as ESP32-C3 SuperMini.

MCU #3 retains its I2C address (0x0A), subsystem role (Database Controller),
and firmware architecture (FreeRTOS tasks, SharedBus, MessageProtocol).
Only the hardware and pin assignments change.

The LOLIN32 Lite breaks out the ESP32's VSPI bus with explicit labels on the
PCB (V_SPI_CLK, V_SPI_Q/MISO, V_SPI_D/MOSI, V_SPI_CS0/SS) — clean
general-purpose pins confirmed against the board pinout with no flash or
JTAG conflicts. This gives ample headroom for all four peripherals.

**Note:** GPIO5 has an onboard blue LED on the LOLIN32 Lite (labeled
V_SPI_CS0/SS on the pinout). Using GPIO5 as SD CS means the LED will
flicker during SPI activity. This is cosmetic — it does not affect function.

---

## New pin assignments for MCU #3

| Function | GPIO | LOLIN32 Lite label | Notes |
|---|---|---|---|
| Shared bus SDA | GPIO8 | GPIO8 | Matches all other MCUs — hub wiring unchanged |
| Shared bus SCL | GPIO9 | GPIO9 | Matches all other MCUs — hub wiring unchanged |
| OLED SDA | GPIO16 | RXD2 | U8g2 SW I2C — free, no special functions |
| OLED SCL | GPIO17 | TXD2 | U8g2 SW I2C — free, no special functions |
| SD MOSI | GPIO23 | V_SPI_D / MOSI | ESP32 default VSPI MOSI |
| SD MISO | GPIO19 | V_SPI_Q / MISO | ESP32 default VSPI MISO |
| SD SCK  | GPIO18 | V_SPI_CLK / SCK | ESP32 default VSPI SCK |
| SD CS | GPIO5  | V_SPI_CS0 / SS  | ESP32 default VSPI CS — onboard LED on this pin |

---

## Impact on shared_config.h

`OLED_SDA_PIN` and `OLED_SCL_PIN` were previously defined in `shared_config.h`
as GPIO3 and GPIO10 — valid for all ESP32-C3 SuperMinis. With MCU #3 now on
a different board, these values are no longer universal. They have been moved
to each MCU's local `config.h`.

MCUs #1, #2, #4, #5 keep GPIO3=SDA, GPIO10=SCL as before.
MCU #3 uses GPIO16=SDA, GPIO17=SCL.

GPIO3 on the LOLIN32 Lite is RX0 (UART0 receive). GPIO10 is connected to
the internal flash SPI interface. Both are unsafe for OLED use on this board.

`shared_config.h` continues to own all values that are truly shared: shared
bus pins (GPIO8/9), MCU addresses, FreeRTOS stack sizes, and heartbeat timing.

---

## SD card library

The Arduino `SD.h` library is used for MCU #3. SdFat exhibited unstable
behaviour during the ESP32-C3 debugging process — crashes in
`spiTransferByteNL` across multiple pin combinations — though this may have
been a consequence of the pin conflicts rather than a library incompatibility.
SD.h with FAT32 on the LOLIN32 Lite is the proven path forward.

SD card is formatted as FAT32 with an 8GB partition on a 64GB physical card.
FAT32 volumes over 32GB are not reliably supported by SD.h or SdFat. The
remaining ~56GB is unallocated. For this project, MCU #3 needs only a few MB.

---

## Consequences

- MCU #3 breadboard replaced with a larger breadboard to accommodate the
  LOLIN32 Lite form factor and leave space for a second SD card module
  (planned for Phase 5 RAID-1 storage redundancy — hardware already available)
- The original ESP32-C3 SuperMini that was MCU #3 is retained for possible
  future use
- platformio.ini for MCU #3: board = esp32dev, upload/monitor port =
  /dev/ttyUSB0 (CH340C USB-to-serial bridge on the board)
- OLED pin constants moved from shared_config.h to per-MCU config.h
- All other MCU firmware, shared libraries, and physical wiring unchanged

## Amendment — 2026-04-18: WeMos LOLIN32 Lite also replaced

The board received and soldered as "ESP32 DevKit" was in fact a **WeMos
LOLIN32 Lite clone** (ESP32-D0WDQ6, CH340C, PCB antenna). The AliExpress
listing was misleading.

The LOLIN32 Lite was found to be incompatible with this project for a
different but equally fundamental reason: **GPIO8 and GPIO9 are connected
to the 32kHz crystal oscillator (Xtal32N/Xtal32P) on this board and are
not available as user GPIO.** The shared inter-MCU I2C bus requires
GPIO8=SDA and GPIO9=SCL on all MCUs — this is a hard architectural
constraint documented in shared_config.h and the hub wiring.

SD card debugging was also attempted on this board. Consistent SdFat
errors (0x17, 0x0C, 0x01) were observed. Breadboard contact failures
caused intermittent behavior masking the real errors. After bypassing
the breadboard with direct jumpers, errors became consistent (0x01 /
CMD1 timeout) but the GPIO8/9 issue made the board a dead end regardless.

**Second replacement: ESP32-WROOM-32 DevKit (38-pin, CP2102, Type-C USB)**
This board has GPIO8/9 confirmed available as user GPIO per the official
Espressif pinout. All other pin assignments (OLED GPIO16/17, SD card
GPIO18/19/23/5, shared bus GPIO8/9) remain identical. PlatformIO target
remains `board = esp32dev`. No firmware changes required.

An ESP32 Terminal Adapter (screw terminals) has also been ordered to
eliminate breadboard contact failures permanently for MCU #3.

## Amendment — 2026-05-07: SD card approach superseded — see ADR-009

SD card debugging continued on the ESP32-WROOM-32 DevKit with SdFat 2.3.1.
CMD0 eventually passed consistently but CMD8 failed on every attempt with
data=0xFF (MISO reading idle/floating — card not driving a response).
Terminal adapter confirmed solid connections. Multiple library configurations,
card formats, and pin combinations exhausted.

After three board replacements and exhaustive SPI debugging across all of
them, the conclusion is that the SD card approach has an unacceptable
reliability cost for this project. The failure mode (CMD8 / voltage check)
is consistent across boards and wiring configurations, suggesting a deeper
incompatibility between the SDXC card and the SdFat init sequence that
is not worth continuing to chase.

**Architecture pivot:** SD card storage abandoned entirely. MCU #3 remains
on the shared I2C bus at 0x0A but delegates all storage to a Raspberry Pi
3B+ connected over UART. See ADR-009 for full reasoning and consequences.

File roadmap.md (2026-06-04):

# 🗺️ Project Roadmap

---

## Phase 1 — Foundation *(Week 1)*

- [x] Development environment setup (VS Code + PlatformIO + ESP32 board support)
- [x] Flash and verify all MCUs individually
- [x] Test OLED displays per subsystem (MCU1 and MCU2 confirmed working)
- [x] Shared OLED library created and working across all MCUs
- [x] PlatformIO workspace configured for all MCUs simultaneously
- [x] Establish basic I2C communication between two MCUs

---

## Phase 1.5 — Hardware Fix *(unplanned, before Phase 2)*

- [x] Replace TwoWire(1) OLED bus with U8g2 SW_I2C (ESP32-C3 has one I2C peripheral)
- [x] Verify OLED + shared bus running simultaneously on MCU #1 and MCU #2
- [x] Extract SharedBus class into shared library with poll() pattern
- [x] Extract MessageProtocol class into shared library with schema validation
- [x] Update all MCU main.cpp files to use config.h pin constants

---

## Phase 2 — Protocol *(Week 2)*

- [x] Implement JSON message format using ArduinoJson + MessageProtocol library
- [x] Connect all 5 MCUs to shared I2C bus (T-shape layout, hub on vertical BB)
- [x] Test MCU #1 ↔ each slave individually (sequential pair tests) ✅

> Note: full 5-MCU simultaneous bus test deferred — see Phase 2.5 below.

---

## Phase 2.5 — Architecture Pivot: FreeRTOS *(complete 2026-04-13)*

The Arduino loop() model was found insufficient for authentic mainframe
subsystem-to-subsystem communication. Key constraint: TwoWire on ESP32-C3
can only be master OR slave per boot — slaves cannot initiate transmissions.
This prevents JES (MCU #4) from talking directly to DASD (MCU #3) without
routing through MCU #1, which distorts the mainframe architecture.

FreeRTOS — already running under Arduino on ESP32 — surfaces as the right
abstraction layer. Tasks map naturally to subsystems, queues model job
scheduling, mutexes protect bus access.

**See ADR-007 for full reasoning and validation results.**

- [x] Identify I2C master/slave constraint via testing
- [x] Document pivot reasoning (ADR-007)
- [x] Validate FreeRTOS multi-master I2C on ESP32-C3 (proof of concept)
- [x] Redesign SharedBus for task-safe operation (mutex + mode switching)
- [x] Validate all three PoC assumptions on real hardware (MCU #1 + MCU #2)
- [x] Design full 5-MCU FreeRTOS task architecture (docs/design/freertos_architecture.md)

---

## Phase 3 — Individual Subsystems *(simple implementations)*

> FreeRTOS task pattern used throughout. Each MCU implemented and tested
> incrementally: receiver + OLED first, then logic, then subsystem task,
> then full flow. See docs/design/freertos_architecture.md for task design.
> Implementation order follows dependency chain: DB first, then Transaction
> Processor, then Job Scheduler, then I/O Controller, then serial console.

- [x] Migrate MCUs #3, #4, #5 to FreeRTOS task pattern (init() API)
- [x] Full 5-MCU simultaneous bus test
- [x] MCU #1: heartbeat task (single sender, all 4 slaves, timestamp-based health tracking)

---

### RPi — Database Controller (address 0x0A)

> ESP32-WROOM-32 DevKit (MCU #3) retired after exhaustive I2C slave
> debugging across three boards and three frameworks. Raspberry Pi 3B+
> replaces it directly on the shared bus at 0x0A via the BCM2837 BSC slave
> peripheral (pigpio bsc_i2c, GPIO18/19). See ADR-011 for full history.
>
> Phase 3 covers bus participation and OLED only. SQLite and Flask are
> Phase 4. Updated per ADR-011 (2026-06-03).

**RPi — Phase 3.1: OLED smoke test**
- [ ] SSD1306 on GPIO2/3 (BSC1 master), static text on screen
      DoD: "DATABASE CTRL / Addr: 0x0A / BOOT OK" persists across resets

**RPi — Phase 3.2: pigpio BSC slave init**
- [ ] pigpio daemon running, `bsc_i2c(0x0A)` armed on GPIO18/19
      DoD: loopback test — RPi sends to itself, callback fires, logged

**RPi — Phase 3.3: HEARTBEAT receive**
- [ ] MCU #1 sends HEARTBEAT broadcast, RPi callback fires and logs it
      DoD: RPi serial/SSH log shows HEARTBEAT received from 0x08, no response sent yet

**RPi — Phase 3.4: HEARTBEAT_ACK round-trip**
- [ ] RPi loads HEARTBEAT_ACK into TX FIFO with ready_byte = 0x01
- [ ] MCU #1 calls sendAndReceive(0x0A), reads ACK, logs success
      DoD: MCU #1 OLED shows RPi alive in heartbeat health display

**RPi — Phase 3.5: sendAndReceive() on MCU #2**
- [ ] sendAndReceive() added to SharedBus — holds busMutex across send + poll loop
- [ ] MCU #2 sends DB_READ stub, polls until ready_byte = 0x01, reads 256 bytes
- [ ] RPi loads stub DB_READ_RESULT (hardcoded balance, no SQLite yet)
      DoD: MCU #2 logs correct stub balance received from 0x0A

**RPi — Phase 3.6: DB_WRITE_ACK stub round-trip**
- [ ] MCU #2 sends DB_WRITE stub, RPi loads stub DB_WRITE_ACK
      DoD: MCU #2 receives ACK within 500ms, logs success

**RPi — Phase 3.7: OLED live updates**
- [ ] oled_worker thread running, display_state updated on each bus event
- [ ] OLED shows: IDLE / DB READ / DB WRITE + last account number
      DoD: OLED updates correctly during a stub DB_READ + DB_WRITE cycle

**RPi — Phase 3.8: timeout path**
- [ ] RPi process killed mid-transaction, MCU #2 poll loop expires
      DoD: MCU #2 returns Status::TIMEOUT within 500ms, logged correctly

---

### Remaining MCUs — Phase 3

- [ ] MCU #2: sequential transaction handling — one transaction at a time (Option A)
      Requires sendAndReceive() from Phase 3.5 above
- [ ] MCU #4: immediate job dispatch — receive JOB_SUBMIT, dispatch to MCU #2 immediately
- [ ] MCU #5: WiFi/HTTP server task, web console (single pending request slot), I2C logic task
- [ ] MCU #1: serial console commands — DEPOSIT/WITHDRAW/BALANCE dispatch to MCU #4
      Requires sendAndReceive() for HEARTBEAT_ACK from Phase 3.4 above
- [ ] End-to-end transaction flow verified: DEPOSIT, WITHDRAW, BALANCE

---

## Phase 4 — Integration and Production Implementations

- [ ] MCU #2: replace sequential logic with state machine (Option B)
- [ ] MCU #4: replace immediate dispatch with priority queue — HIGH/MEDIUM/LOW ordering
- [ ] MCU #5: expand pending request table to 4 slots (from 1)
- [x] Heartbeat and health monitoring — MCU #1 flags non-responding subsystems on OLED
- [ ] Single retry on BusError::NOT_FOUND before reporting failure
- [ ] Full banking scenarios verified on real hardware
- [ ] MCU #1: WiFi web dashboard
- [ ] RTC timestamps on all transaction log entries (DS1307 on MCU #1)
- [ ] RPi: db.py — DB_READ handler (SQLite accounts table, balance query)
- [ ] RPi: db.py — DB_WRITE handler (write-ahead log pattern, balance update, COMMITTED)
- [ ] RPi: web_server.py — Flask transaction history table at :5000
- [ ] RPi: rsync cron job — SQLite backup to dev PC every 10 minutes

---

## Phase 5 — Advanced Features

- [ ] Atomic TRANSFER transactions (two-phase commit across MCU #2 and RPi)
- [ ] Crash recovery — RPi replays PENDING transactions from SQLite log on boot
- [ ] Storage redundancy — periodic backup to USB stick on RPi
- [ ] Load testing — 50 sequential transactions without dropping
- [ ] Failure simulation — physically disconnect a subsystem, observe timeout propagation
- [ ] Priority job scheduling stress test — mixed HIGH/MEDIUM/LOW queue under load
- [ ] Binary message protocol — replace JSON with compact binary format
- [ ] USB-to-I2C PC dispatcher *(in consideration)*
- [ ] MCU #1 serial console account management — create/delete accounts at runtime
- [ ] Account balance limits and overdraft rules

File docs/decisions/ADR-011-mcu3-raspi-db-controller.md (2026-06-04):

# ADR-011: Raspberry Pi 3B+ replaces MCU #3 on shared bus

## Status
Accepted — 2026-06-03
Supersedes ADR-009 (RPi UART backend) and ADR-010 (pure ESP-IDF framework)

---

## Context

MCU #3 (ESP32-WROOM-32 DevKit) was designed to be the Database Controller
subsystem on the shared inter-MCU I2C bus at address 0x0A. Its role was to
receive DB_READ and DB_WRITE requests from other MCUs, proxy them to a
Raspberry Pi 3B+ over UART, and return results on the shared bus.

The blocking issue was Phase 3.1: initializing an I2C slave on GPIO8/9 via
`i2c_new_slave_device()` (IDF 5.4.0, slave driver v2). Every attempt caused
a `TG1WDT_SYS_RESET` before the function returned.

### Investigation history — what was tried across all sessions

**Arduino Wire.begin() in slave mode (ADR-010)**
Caused TG1WDT on both Wire (bus 0) and Wire1 (bus 1). Root cause confirmed
from source code: `i2cSlaveInit()` creates an internal FreeRTOS task at
priority 20, which starves IDLE1 on the dual-core WROOM and triggers the
Task Watchdog. Not fixable without modifying the framework.

**IDF 4.4.7 i2c_driver_install() in slave mode (ADR-010)**
Same TG1WDT result. Root cause not fully traced. Disqualified.

**pioarduino (arduino-esp32 3.x, IDF 5.5.x) with i2c_new_slave_device() (ADR-010)**
arduino-esp32 auto-initializes Wire on GPIO8/9 before setup() runs, claiming
those pins in the IDF GPIO matrix before user code can execute. Three
workarounds attempted; all failed. The Wire auto-init is a framework-level
constraint that cannot be suppressed from user code.

**Pure ESP-IDF (framework = espidf, IDF 5.4.0) with i2c_new_slave_device() (ADR-010, Phase 3.1)**
Eliminated the Arduino GPIO conflict at root. i2c_new_slave_device() still
caused TG1WDT_SYS_RESET on every boot before returning. Extensive isolation
testing ruled out: bus activity from other MCUs, concurrent OLED task, callback
registration, mutex contention, and GPIO idle state.

Investigation into the hang location revealed:
- Both CPUs were inside panicHandler() at WDT reset time (addr2line confirmed)
- A panic fires inside i2c_new_slave_device() before it returns
- The panic handler deadlocks on the dual-core inter-core stall mechanism
  before printing anything, then the WDT fires again and resets the chip
- CONFIG_ESP_SYSTEM_PANIC_PRINT_HALT was correctly set but ineffective
  because the WDT fires before the panic handler completes output
- Disabling CONFIG_ESP_TASK_WDT_INIT produced complete silence — no output
  at all, indicating the panic handler itself halts before reaching UART
- Single-core mode (CONFIG_FREERTOS_UNICORE=y) also produced no output

Source code investigation established:
- SOC_I2C_SUPPORT_SLAVE=1 on plain ESP32 — slave is supported at SOC level
- SOC_I2C_SLAVE_CAN_GET_STRETCH_CAUSE is absent on plain ESP32
- The entire v2 slave test suite (test_i2c_slave_v2.c) is guarded by
  SOC_I2C_SLAVE_CAN_GET_STRETCH_CAUSE — Espressif never runs v2 slave
  tests on plain ESP32
- The official i2c_slave_network_sensor example explicitly excludes plain
  ESP32 from its supported targets
- Stretch LL functions are empty stubs on plain ESP32 — not the hang cause
- The exact line inside i2c_new_slave_device() where the panic originates
  remains unidentified due to the panic handler output failure

The next diagnostic step would be adding ESP_LOGI prints directly into
i2c_slave_v2.c to narrow the hang to a single statement. This is technically
feasible but represents continued investment in a path with no confirmed
end — each finding has revealed a new unknown rather than a fix.

### Decision to stop

MCU #3 I2C slave initialization has consumed weeks of debugging time across
multiple boards (ESP32-C3 SuperMini → WeMos LOLIN32 Lite → ESP32-WROOM-32
DevKit), multiple frameworks (Arduino → pioarduino → pure ESP-IDF), and
multiple driver versions (Wire → i2c_driver_install → i2c_new_slave_device).
Each pivot was justified and well-documented. The current blocker is deep
inside an untested IDF driver path on a chip variant Espressif does not
officially validate for this use case.

The cost of continuing to chase this is no longer justified for a learning
project. The pivot to Raspberry Pi is a deliberate architectural decision,
not a workaround.

### Why RPi as I2C slave was previously rejected (ADR-009)

ADR-009 rejected the RPi-as-I2C-slave option with the reasoning:
"Linux I2C slave driver support on RPi is notoriously unreliable and would
likely reproduce the same debugging spiral in a different form."

That concern remains valid. However, the comparison has changed. The ESP32
debugging environment — no working panic output, WDT masking all diagnostics,
untested driver paths — is maximally opaque. Linux, by contrast, provides
dmesg, strace, readable error messages, and mature Python libraries.
If Linux I2C slave proves difficult, the debugging surface is far more
transparent.

Additionally, the BCM2837 SoC on the RPi 3B+ contains a dedicated BSC
(Broadcom Serial Controller) slave peripheral, accessible via the pigpio
library's `bsc_i2c()` function. This is hardware-backed slave support —
not bit-banging — and has confirmed working reports on RPi 3 hardware
communicating with Arduino masters. The risk of a new debugging spiral
exists and is accepted as preferable to continuing the current one.

---

## Decision

The Raspberry Pi 3B+ replaces MCU #3 (ESP32-WROOM-32) entirely on the
shared inter-MCU I2C bus. The RPi joins the bus at address 0x0A and takes
over the Database Controller role directly.

The ESP32-WROOM-32 DevKit is retired from this project. See ADR-008 for
its hardware history.

The UART link between MCU #3 and the RPi (ADR-009) is no longer needed.
Existing UART wiring (RPi GPIO14/15) should be removed after the new
I2C wiring is confirmed working.

All other MCUs (#1, #2, #4, #5) are unaffected. They continue to send
DB_READ and DB_WRITE to address 0x0A and receive results in return.
The change is invisible to the rest of the bus.

---

## Hardware

### RPi I2C slave (shared bus)

The BCM2837 BSC slave peripheral is hardwired to GPIO18 (SDA) and GPIO19
(SCL) — these pin assignments are fixed in silicon and cannot be changed
in software. The RPi connects to the shared bus hub via these two pins.

```
Shared bus hub (SDA/SCL rails)
    │
    ├── MCU #1  GPIO8/9   (existing)
    ├── MCU #2  GPIO8/9   (existing)
    ├── MCU #4  GPIO8/9   (existing)
    ├── MCU #5  GPIO8/9   (existing)
    └── RPi     GPIO18/19 (BSC slave — new)

Pull-ups: existing 5kΩ on hub SDA and SCL — unchanged.
Voltage: RPi GPIO18/19 are 3.3V — matches ESP32-C3. No level shifting needed.
```

### RPi OLED (private display)

A plain SSD1306 128×64 OLED connects to the RPi via the BSC1 master
peripheral on GPIO2 (SDA) and GPIO3 (SCL). This is a separate wire pair
from the shared bus and does not connect to the hub.

```
RPi GPIO2/3 → SSD1306 OLED (private, not on shared bus hub)
```

GPIO18/19 (BSC slave) and GPIO2/3 (BSC1 master) are two separate hardware
peripherals on the BCM2837. They do not interfere with each other.

---

## Protocol

### Why the RPi never needs to initiate

In the existing SharedBus design, MCUs switch between slave (listening) and
master (sending) roles at runtime. When a slave MCU responds to a message,
it temporarily becomes the bus master, addresses the target, and pushes
the response.

The RPi does not need this pattern. Every message the RPi sends is a
response to a prior request from an MCU. The I2C protocol supports this
without the RPi ever generating a START condition: the requesting MCU
remains master for the entire exchange, using a master-read transaction
to clock out the RPi's response from the BSC slave TX FIFO.

This means the RPi operates as a pure I2C slave throughout. The BSC slave
peripheral is sufficient — no master role is needed on the shared bus.

### Request-response flow

Every RPi interaction follows this two-transaction pattern:

```
MCU (master write):   START → addr 0x0A + W → payload bytes → STOP
                      [RPi processes request, loads response into TX FIFO]
MCU (master read):    START → addr 0x0A + R → clocks out 256 bytes → STOP
```

The MCU drives SCL for both transactions. The RPi drives SDA only during
the read transaction, from its TX FIFO.

### Readiness signalling

The RPi cannot pause the master's read clock. If the TX FIFO is not yet
loaded when the MCU issues the read, the BSC slave returns 0xFF bytes.
To avoid this, a 1-byte ready flag precedes all responses:

- `0x00` — not ready, try again
- `0x01` — response follows in bytes 1–255

The MCU polls `requestFrom(0x0A, 256)` in a loop with short delays until
byte[0] == 0x01 or the 500ms timeout elapses. On timeout, the MCU returns
`Status::TIMEOUT` to the caller, consistent with existing error handling.

The MCU always reads exactly 256 bytes — the maximum I2C buffer size
already used throughout the system. Trailing bytes beyond the JSON payload
are ignored by the parser.

### DB_READ flow

```
MCU #2                              RPi (pigpio BSC slave, GPIO18/19)
  │                                         │
  │── send(0x0A, DB_READ) ─────────────────►│  write transaction
  │                                         │  pigpio EVENT_BSC fires
  │                                         │  parse request
  │                                         │  query SQLite (Phase 4+)
  │                                         │  load DB_READ_RESULT into TX FIFO
  │                                         │  set ready_byte = 0x01
  │                                         │
  │  ┌── poll loop (500ms timeout) ─────────┤
  │  │  requestFrom(0x0A, 256) ────────────►│  read transaction
  │  │  check byte[0]                       │  RPi drives SDA from TX FIFO
  │  │  0x00 → vTaskDelay(10ms), retry      │
  │  │  0x01 → break                        │
  │  └──────────────────────────────────────┘
  │                                         │
  │  parse bytes[1..255] → DB_READ_RESULT   │
  │  [timeout → Status::TIMEOUT]            │
```

### DB_WRITE flow

```
MCU #2                              RPi
  │                                         │
  │── send(0x0A, DB_WRITE) ────────────────►│  write transaction
  │                                         │  write WAL entry (PENDING)
  │                                         │  update balance
  │                                         │  mark COMMITTED
  │                                         │  load DB_WRITE_ACK into TX FIFO
  │                                         │  set ready_byte = 0x01
  │                                         │
  │  ┌── poll loop (500ms timeout) ─────────┤
  │  │  requestFrom(0x0A, 256) ────────────►│
  │  │  check byte[0] → break on 0x01       │
  │  └──────────────────────────────────────┘
  │                                         │
  │  parse bytes[1..255] → DB_WRITE_ACK     │
```

### HEARTBEAT flow

```
MCU #1                              RPi
  │                                         │
  │── send(0x0A, HEARTBEAT) ───────────────►│  write transaction
  │                                         │  load HEARTBEAT_ACK into TX FIFO
  │                                         │  set ready_byte = 0x01
  │                                         │  (no SQLite — fixed response)
  │                                         │
  │  vTaskDelay(20ms)                       │  [fixed delay: no SQLite latency]
  │  requestFrom(0x0A, 256) ───────────────►│
  │  parse bytes[1..255] → HEARTBEAT_ACK    │
```

HEARTBEAT_ACK requires no database query. A fixed 20ms delay before the
single read attempt is sufficient to cover pigpio callback latency.
No polling loop is needed.

---

## MCU firmware changes required

### New SharedBus method: sendAndReceive()

```cpp
// Sends a message to target, then polls requestFrom() until the ready
// byte (byte[0]) == 0x01 or timeoutMs elapses. On success, reads exactly
// 256 bytes into rxBuf. Returns Status::OK or Status::TIMEOUT.
//
// busMutex is held across the full send + poll sequence — no other task
// can interleave a bus operation between the write and read transactions.
uint8_t sendAndReceive(uint8_t target,
                       const char* txMsg,
                       char* rxBuf,
                       uint32_t timeoutMs = 500);
```

Required on: MCU #2 (DB_READ, DB_WRITE), MCU #1 (HEARTBEAT).

MCU #2 logic task replaces the pattern:
```
send(DB_READ) → block on inboundQueue waiting for DB_READ_RESULT
```
with:
```
sendAndReceive(DB_READ, rxBuf) → parse rxBuf directly
```

The inboundQueue path (poll → receive pushed result) is not used for
RPi interactions. The RPi never pushes — it only responds to reads.

---

## RPi software architecture

See `docs/design/raspi_architecture.md` for the full thread design.

Summary: three Python threads (bus_worker, oled_worker, flask — Phase 4+)
communicating via `queue.Queue` and `threading.Lock`, mirroring the
FreeRTOS task + queue pattern used on the MCUs. The pigpio EVENT_BSC
callback is a producer that puts incoming requests onto the bus queue;
the bus_worker thread owns all SQLite access and TX FIFO loading.

---

## Repo structure

```
code/
  raspi-db-server/
    CLAUDE.md           — RPi setup steps, design notes, DoD per phase
    src/
      bus_slave.py      — pigpio bsc_i2c setup, EVENT_BSC callback, TX FIFO protocol
      db.py             — SQLite read/write, WAL mode (Phase 4+)
      web_server.py     — Flask transaction history at :5000 (Phase 4+)
      oled.py           — luma.oled SSD1306 driver on GPIO2/3
    schema/
      schema.sql        — accounts + transactions tables (Phase 4+)
```

---

## What is decided

- RPi 3B+ is the Database Controller at I2C address 0x0A
- RPi connects to shared bus via GPIO18/19 (BSC slave, pigpio bsc_i2c)
- RPi OLED connects via GPIO2/3 (BSC1 master, separate from shared bus)
- RPi owns SQLite storage and Flask web interface directly (Phase 4+)
- ESP32-WROOM-32 DevKit is retired — see ADR-008 for hardware history
- Shared bus address 0x0A is preserved — no changes to other MCUs
- sendAndReceive() added to SharedBus for MCU #1 and MCU #2

## What is deferred

- SQLite implementation (db.py) — Phase 4
- Flask web interface (web_server.py) — Phase 4
- Crash recovery (PENDING transaction replay) — Phase 5
- rsync backup to dev PC — Phase 4

---

## Impact on existing documents

- ADR-009: superseded. UART protocol and wiring are void.
- ADR-010: superseded. ESP-IDF framework decision and shared_bus_wroom
  implementation are inactive. Code preserved in repo for reference.
- roadmap.md: MCU #3 phases replaced per this ADR.
- requirements.md: no functional requirement changes.
- shared_config.h: no changes — bus address 0x0A unchanged.
- CLAUDE.md (MCU #3): retired entry. RPi has its own CLAUDE.md.

---

## Consequences

- MCU #3 firmware (shared_bus_wroom, oled_display_wroom, main.cpp) is
  preserved in the repo but inactive. Do not delete — documents the
  investigation and may be referenced in future sessions.
- UART wiring (RPi GPIO14/15 ↔ former MCU #3 GPIO18/19) should be
  removed after new I2C wiring is confirmed working.
- RPi now has two hardware responsibilities: I2C slave on shared bus
  (GPIO18/19), and SSD1306 OLED (GPIO2/3). Both on the same device —
  simpler than the MCU #3 + RPi split, not more complex.
- MCU #2 and MCU #1 logic tasks require minor changes to use
  sendAndReceive() instead of send() + poll() for RPi interactions.
- RPi must be booted before MCU #1 and MCU #2 start processing —
  both handle RPi-down gracefully via the 500ms timeout.

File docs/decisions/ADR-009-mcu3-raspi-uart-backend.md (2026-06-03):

# ADR-009: Raspberry Pi 3B+ replaces SD card as MCU #3 storage backend

## Status
Accepted — 2026-05-07
Superseded by ADR-011 — 2026-06-03

## Supersedes
ADR-008 (hardware substitution — SD card approach)

---

## Context

MCU #3 (Database Controller) requires persistent storage for account balances
and an append-only transaction log. The original design used an SPI SD card
attached directly to the MCU. After three board replacements and exhaustive
debugging across multiple library configurations, card formats, and pin
combinations, the SD card approach was abandoned. See ADR-008 for the full
hardware debugging history.

The core requirement has not changed:
- Store and retrieve account balances by account number
- Append transaction log entries with UUID identifiers
- Support unbounded transaction history (rules out internal flash)
- Eventually serve transaction history via web interface

### Options considered

**Option A: Continue SD card debugging**
CMD0 now passes consistently on the ESP32-WROOM-32 DevKit. CMD8 fails with
data=0xFF on every attempt — MISO reading idle, card not driving a response.
This has been consistent across boards and wiring configurations. The cost
of continuing to chase this is not justified given the time already spent.
Rejected.

**Option B: Raspberry Pi as I2C slave replacing MCU #3 entirely**
RPi joins the shared bus at address 0x0A and runs a Python I2C slave. Solves
storage and web interface in one device. Rejected: Linux I2C slave driver
support on RPi is notoriously unreliable and would likely reproduce the same
debugging spiral in a different form.

**Option C: MCU #3 stays on bus, RPi connected over WiFi**
MCU #3 forwards DB requests to RPi over TCP/IP. Rejected: WiFi adds 20–100ms
latency per request plus connection management complexity. UART is simpler
and faster for a point-to-point link.

**Option D: MCU #3 stays on bus, RPi connected over UART**
MCU #3 remains the I2C slave at 0x0A — no change visible to any other MCU.
When it receives DB_READ or DB_WRITE, it forwards the request to RPi over
a dedicated UART link (newline-terminated JSON), waits for a response with
timeout, and returns the result on the shared bus. RPi owns SQLite and Flask.
Selected.

---

## Decision

MCU #3 retains its role as I2C slave at address 0x0A and continues to
participate in the shared bus exactly as designed. All other MCUs are
unaffected — they still send DB_READ and DB_WRITE to 0x0A and receive
DB_READ_RESULT and DB_WRITE_ACK in return.

Storage is delegated to a **Raspberry Pi 3B+** connected to MCU #3 via
**UART1** (GPIO18=TX, GPIO19=RX, shared GND). The RPi runs:
- A Python UART listener that owns all SQLite access
- A Flask web server that reads the same SQLite database
- Periodic rsync of the SQLite file to the development PC for backup

### UART protocol

Messages are newline-terminated JSON. MCU #3 sends a request, RPi responds,
MCU #3 waits up to 500ms before returning `Status::TIMEOUT` to MCU #2.

Request from MCU #3 to RPi:
```json
{"op":"read","ac":"12345678"}
{"op":"write","ac":"12345678","nb":60000,"tt":1,"mid":"uuid"}
```

Response from RPi to MCU #3:
```json
{"bal":50000,"st":0}
{"st":0}
```

### Write-ahead log pattern on RPi

For every DB_WRITE:
1. RPi writes transaction to log table with `status=PENDING`
2. RPi updates account balance
3. RPi marks transaction `status=COMMITTED`
4. RPi responds to MCU #3

On RPi boot, any `PENDING` entries that never reached `COMMITTED` indicate
an interrupted transaction. These can be replayed or flagged for review.
This mirrors the write-ahead log pattern originally planned for the SD card.

### Redundancy

SQLite WAL mode is enabled — safe concurrent access between UART listener
and Flask. Periodic rsync to development PC over WiFi provides a second
copy of the database without additional hardware.

---

## New pin assignments for MCU #3

| Function | GPIO | Notes |
|---|---|---|
| Shared bus SDA | GPIO8 | Unchanged — hub wiring unchanged |
| Shared bus SCL | GPIO9 | Unchanged — hub wiring unchanged |
| OLED SDA | GPIO16 | U8g2 SW I2C — unchanged |
| OLED SCL | GPIO17 | U8g2 SW I2C — unchanged |
| UART TX (to RPi RX) | GPIO18 | Former SD SCK pin — now UART1 TX |
| UART RX (from RPi TX) | GPIO19 | Former SD MISO pin — now UART1 RX |
| ~~SD MOSI~~ | ~~GPIO23~~ | Freed — not connected |
| ~~SD CS~~ | ~~GPIO5~~ | Freed — not connected |

RPi GPIO14 (TX) → MCU #3 GPIO19 (RX)
RPi GPIO15 (RX) → MCU #3 GPIO18 (TX)
Shared GND required.

Voltage levels match: both ESP32 and RPi GPIO are 3.3V. No level shifting needed.

---

## RPi configuration requirements

- Raspberry Pi OS Lite (no desktop)
- Hardware UART assigned to GPIO pins: add `dtoverlay=disable-bt` to
  `/boot/config.txt` — frees hardware UART (ttyAMA0) from Bluetooth,
  exposes it on GPIO14/15. Bluetooth moves to mini-UART (acceptable for
  BT bandwidth).
- Serial console on UART disabled (would conflict with application use)
- Python 3 + Flask (`pip install flask`)
- SQLite3 (included in Python standard library)
- SQLite WAL mode enabled at application startup
- Dedicated 5V/3A power supply — do NOT power from bench supply shared
  with MCUs (RPi 3B+ can draw up to 2.5A under load)

---

## Repo structure

RPi code lives in the project repo alongside MCU firmware:

```
code/
  raspi-db-server/
    CLAUDE.md         — setup steps, design notes, DoD per step
    src/
      db_server.py    — UART listener + SQLite read/write
      web_server.py   — Flask web interface
    schema/
      schema.sql      — SQLite schema (accounts + transactions tables)
```

---

## Impact on MCU #3 firmware

- SD card task replaced with UART task (same queue pattern: uartQueue +
  uartResultQueue replacing sdQueue + sdResultQueue)
- `config.h`: SD pin definitions removed, UART pin definitions added
- `platformio.ini`: SdFat removed, SDFAT_FILE_TYPE and SPI_DRIVER_SELECT
  flags removed
- Logic task: unchanged externally — still handles DB_READ/DB_WRITE,
  still puts requests on queue and waits for result
- MCU #2 logic task: `xQueueReceive` on result queue must use a timeout
  (500ms recommended) — if RPi is down, MCU #3 returns Status::TIMEOUT
  to MCU #2 rather than blocking forever

## Impact on other MCUs

None. MCU #3 still responds to DB_READ and DB_WRITE at address 0x0A.
The storage backend is an internal implementation detail.

---

## Consequences

- SD card module, SD card, and terminal adapter SD wiring are no longer
  needed for MCU #3. Hardware can be retained for future use.
- RPi requires its own dedicated power supply
- RPi must be booted before MCU #3 starts processing DB requests —
  MCU #3 handles RPi-down gracefully via UART timeout
- Web interface for transaction history is now a first-class deliverable
  (Flask on RPi), not deferred to Phase 4
- rsync redundancy to PC is simple to implement and provides backup
  without additional hardware
- Phase 5 RAID-1 dual SD card item is obsolete and removed from roadmap

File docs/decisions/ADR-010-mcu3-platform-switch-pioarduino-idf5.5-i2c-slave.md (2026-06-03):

# ADR-010: MCU #3 framework switch to pure ESP-IDF (framework = espidf)

## Status
Accepted — 2026-05-16 (revised 2026-05-21)
Superseded by ADR-011 — 2026-06-03

## Amends
ADR-009 (OLED pin note — see below)

---

## Context

MCU #3 (ESP32-WROOM-32) needs to operate as an I2C slave at address 0x0A
on the shared inter-MCU bus (GPIO8/9). All previous attempts to initialize
I2C slave mode failed with either a TG1WDT (Timer Group 1 Watchdog) reset
or a silent GPIO matrix conflict.

### Investigation — what was tested

**Attempt 1: Arduino `Wire.begin()` in slave mode**
Both `Wire` (bus 0) and `Wire1` (bus 1) were tested. Both caused TG1WDT.

Root cause confirmed by source code (`esp32-hal-i2c-slave.c`): `Wire.begin()`
in slave mode calls `i2cSlaveInit()`, which calls `xTaskCreate(i2c_slave_task,
..., priority=20, ...)`. A task at priority 20 on Core 1 prevents IDLE1 from
being scheduled. TG1WDT monitors each core's idle task and fires if IDLE1
does not receive CPU time within ~1 second. Single-core MCUs (#1/#2/#4/#5,
ESP32-C3) are unaffected — no IDLE1 to starve.

**Attempt 2: IDF 4.4.7 `i2c_driver_install()` in slave mode**
Same result — TG1WDT fired inside the call, before the success print was
reached. Root cause not fully traced (candidate: behavior inside
`i2c_isr_register()` or a 4.4.7-specific bug). Not pursued further —
the outcome was sufficient to disqualify IDF 4.4.7.

**Attempt 3: pioarduino (arduino-esp32 3.x, IDF 5.5.x) with `i2c_new_slave_device()`**
`i2c_new_slave_device()` (IDF 5.2+, slave driver v2, interrupt-driven, no
internal task) eliminates the WDT root cause. However, arduino-esp32 3.x
auto-initializes Wire (I2C_NUM_0) on GPIO8/9 before `setup()` runs, claiming
those pins in the IDF GPIO matrix before our code executes.

Sub-attempts to resolve the GPIO matrix conflict:
1. Change `conf.i2c_port` to I2C_NUM_1 — no effect (conflict is at GPIO
   level, not peripheral number level)
2. Swap init order: `sharedBus.init()` before `oled.begin()` — no effect
   (Wire is initialized by the framework before `setup()` runs)
3. Call `gpio_reset_pin(GPIO_NUM_8/9)` before `sharedBus.init()` — board
   hung, no serial output, OLED blank. `gpio_reset_pin()` conflicts with
   something the framework depends on at that point in boot.

All three workarounds failed. The Wire auto-init happens at the framework
bootstrap level, before any user code can intervene.

### Root cause summary

The Arduino layer (any version) auto-initializes Wire on GPIO8/9 before
user code runs. This is by design in arduino-esp32 and cannot be suppressed
at the user level without modifying the framework itself. Any solution that
retains the Arduino layer is fighting this constraint indefinitely.

### Why `i2c_new_slave_device()` is the correct slave API

IDF 4.4.7 `i2c_driver_install()` in slave mode creates an internal FreeRTOS
task at priority 20 (Wire path, confirmed) and has additional instability
on dual-core ESP32-WROOM (observed but not fully traced). IDF 5.2 introduced
`i2c_new_slave_device()` (slave driver v2): interrupt-driven, no internal task,
push-based receive via ring buffer and ISR callback. This is the correct
design for a slave device in a FreeRTOS system with managed task priorities.

`CONFIG_I2C_ENABLE_SLAVE_DRIVER_VERSION_2=y` must be set in `sdkconfig.defaults`
to activate driver v2. In IDF 6.0, slave driver v1 is removed and v2 is the
only path — our choice is forward-compatible.

---

## Decision

Switch MCU #3 to **`framework = espidf`** on the official PlatformIO
`espressif32` platform, pinned to v6.10.0 (IDF 5.4):

```ini
[env:mcu3]
platform = espressif32 @ 6.10.0
framework = espidf
board = esp32dev
monitor_speed = 921600
upload_port = /dev/serial/by-id/usb-Silicon_Labs_CP2102_USB_to_UART_Bridge_Controller_0001-if00-port0
monitor_port = /dev/serial/by-id/usb-Silicon_Labs_CP2102_USB_to_UART_Bridge_Controller_0001-if00-port0
```

### Why not pioarduino (previous intermediate decision)

pioarduino (arduino-esp32 3.x, IDF 5.5.x) was considered as a lower-effort
path: retain Arduino APIs, gain IDF 5.5. Rejected because it does not solve
the root cause — the GPIO matrix conflict exists in any Arduino-layer build
regardless of IDF version. pioarduino provides the right IDF version but
the wrong framework layer.

### Why not espressif32 @ 7.0.0 (IDF 6.0)

espressif32 v7.0.0 (IDF 6.0) was released April 2026 and is now the default
when `platform = espressif32` is unpinned. Our slave API (`i2c_new_slave_device()`,
driver v2) survives into IDF 6.0 — slave driver v1 was removed, v2 was not.
However, IDF 6.0 has additional breaking changes (MbedTLS v4, C/C++ standard
upgrades) that have not been evaluated for this project. Pinning to 6.10.0
(IDF 5.4) gives a stable, known-good base. Upgrading to IDF 6.0 is deferred
until a dedicated test session.

### Platform line rationale

`espressif32 @ 6.10.0` with `framework = espidf`:
- PlatformIO downloads vanilla IDF 5.4 toolchain on first build — no manual
  installation required
- All source files are listed in `main/CMakeLists.txt` via `idf_component_register()`
- Configuration overrides go in `sdkconfig.defaults` (committed); `sdkconfig`
  itself is generated and should not be committed
- `managed_components/` and `dependencies.lock` are generated — not committed

### Shared bus library

`shared_bus_wroom` is rewritten from scratch for pure ESP-IDF. No Arduino
dependencies. Same public API as `shared_bus` (ESP32-C3 MCUs): `init()`,
`send()`, `poll()`. Internal implementation:
- `init()`: calls `i2c_new_slave_device()` on I2C_NUM_0 / GPIO8/9, registers
  ISR callback, creates FreeRTOS semaphore
- `poll()`: blocks on semaphore; ISR callback gives semaphore on receive,
  copies bytes from ring buffer to internal buffer
- `send()`: calls `i2c_slave_write()` to pre-load TX buffer

`CONFIG_I2C_ENABLE_SLAVE_DRIVER_VERSION_2=y` required in `sdkconfig.defaults`.
Include `driver/i2c_slave.h` — do NOT include `driver/i2c.h` (old driver);
they conflict at link time.

### OLED

`oled_display_wroom` is written from scratch for pure ESP-IDF.
Uses U8g2 in HAL-callback mode:
- I2C master on I2C_NUM_1 / GPIO16/17 via `i2c_new_master_bus()` +
  `i2c_master_transmit()` (new IDF 5.x master API — no deprecated calls)
- Two callbacks provided to U8g2 setup function:
  `u8x8_byte_i2c_cb` (sends bytes over I2C_NUM_1)
  `u8x8_gpio_delay_cb` (handles reset pin and delays via `vTaskDelay`)
- No community HAL library (all existing ones use deprecated `i2c_driver_install()`)

### Debug output

`ESP_LOGI` / `ESP_LOGW` / `ESP_LOGE` (IDF logging macros) replace
`Serial.print`. Output appears on UART0 (USB/CP2102) at 921600 baud.
UART1 (GPIO18/19) is reserved exclusively for RPi communication.

---

## Impact on MCU #3

- `platformio.ini`: platform = espressif32 @ 6.10.0, framework = espidf
- `CMakeLists.txt` (root + main/): required, created from scratch
- `sdkconfig.defaults`: `CONFIG_I2C_ENABLE_SLAVE_DRIVER_VERSION_2=y` minimum
- `shared_bus_wroom.h/.cpp`: rewritten, no Arduino dependencies
- `oled_display_wroom.h/.cpp`: rewritten, U8g2 HAL-callback mode, new IDF master API
- `main.cpp`: `app_main()` replaces `setup()`/`loop()`; no `vTaskStartScheduler()`

## Impact on other MCUs

None. Framework change is isolated to MCU #3's `platformio.ini`.

---

## Consequences

- No Arduino APIs (Serial, Wire, delay) available in MCU #3 build.
  Replacements: `uart_driver_install()`, `i2c_new_*`, `vTaskDelay()`.
- U8g2 HAL must be written once; it is ~60 lines and well-understood.
- `espressif32` is the official Espressif/PlatformIO platform — lower
  maintenance risk than pioarduino.
- The I2C slave v2 API (`i2c_new_slave_device()`) is the forward-compatible
  path in IDF 6.0+ — this decision does not create future upgrade debt.
- IDF 6.0 upgrade path exists (espressif32 @ 7.0.0) but requires a dedicated
  evaluation session before adoption.

---

## Amendment note for ADR-009

ADR-009 pin table lists OLED GPIO16/17 as "U8g2 SW I2C". Under pure ESP-IDF,
OLED is on hardware I2C_NUM_1 (GPIO16/17) using the new IDF master API.
SW I2C (bit-banged) is not used.

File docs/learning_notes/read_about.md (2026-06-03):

# ISR (freertos vs. espidf approach)

**The core problem both patterns solve:**

An ISR (Interrupt Service Routine — a function that runs when hardware signals an event) must be short and never block. But it needs to wake a sleeping task. FreeRTOS provides `xSemaphoreGiveFromISR()` for this — but after giving the semaphore, the scheduler needs to know whether to immediately switch to the newly-woken task, or finish the ISR and return to whatever was running before.

That decision requires `portYIELD_FROM_ISR`. The two patterns differ in **who calls it**.

---

**Pattern 1 — Raw FreeRTOS (you manage everything)**

```
Hardware event fires
        │
        ▼
┌─────────────────────────────────────────┐
│  your ISR function                      │
│                                         │
│  BaseType_t woken = pdFALSE;            │
│  xSemaphoreGiveFromISR(sem, &woken);    │◄── woken may become pdTRUE
│                                         │    if a task was waiting
│  portYIELD_FROM_ISR(woken);            │◄── YOU call this
│  // nothing after this line             │    triggers context switch
└─────────────────────────────────────────┘    if woken == pdTRUE
        │
        ▼
   ISR exits
        │
        ├─── woken == pdFALSE ──► return to interrupted task
        │
        └─── woken == pdTRUE  ──► switch to woken task immediately
```

You own the full sequence. `portYIELD_FROM_ISR` is the last thing that runs — nothing after it is guaranteed to execute.

---

**Pattern 2 — ESP-IDF callback (IDF manages the yield)**

```
Hardware event fires
        │
        ▼
┌─────────────────────────────────────────┐
│  IDF internal ISR handler               │
│  (registered by i2c_new_slave_device)   │
│                                         │
│  ... IDF reads hardware FIFO ...        │
│  ... copies to ringbuffer ...           │
│                                         │
│  bool woken = your_callback(...);      │◄── IDF calls YOUR function
│                                         │
│  portYIELD_FROM_ISR(woken);            │◄── IDF calls this, not you
└─────────────────────────────────────────┘
        │
        ▼
   ISR exits
        │
        ├─── woken == false ──► return to interrupted task
        │
        └─── woken == true  ──► switch to woken task immediately

        Your callback (on_receive):
        ┌─────────────────────────────────────────┐
        │  memcpy from evt_data->buffer           │
        │  _rxLen = evt_data->length              │
        │                                         │
        │  BaseType_t woken = pdFALSE;            │
        │  xSemaphoreGiveFromISR(sem, &woken);    │
        │                                         │
        │  return woken == pdTRUE;               │◄── hand result to IDF
        └─────────────────────────────────────────┘
```

Your callback does its work and returns a `bool`. IDF takes that bool and calls `portYIELD_FROM_ISR` itself, after your callback returns cleanly.

---

**Why IDF wraps it this way:**

IDF's internal ISR handler does work before calling your callback — reading the hardware FIFO, managing the ringbuffer. It needs to run `portYIELD_FROM_ISR` *after all of that*, not in the middle of it. If you called `portYIELD_FROM_ISR` inside your callback, you'd be yielding before IDF finishes its own cleanup. Handing the bool back lets IDF sequence things correctly.

---

**The key insight:**

Both patterns produce identical runtime behavior. The difference is purely about **who is responsible for calling `portYIELD_FROM_ISR`** and **when** it's safe to call it. In Pattern 1 you control the whole ISR. In Pattern 2 IDF controls the ISR and gives you a hook inside it.

---

## oled display code: new vs old driver

old driver uses c++ object member, new driver requires singleton

On the singleton pattern questione:
The other MCUs' `OledDisplay` wraps a `U8G2_SSD1306_128X64_NONAME_F_SW_I2C` C++ object directly as a member — u8g2's Arduino-style C++ API handles the callback internally. No singleton needed there.
For `OledDisplayWroom` we're using the C API with explicit callbacks — so we do need the bus handle and device handle accessible from a static callback. The singleton pattern from `SharedBusWroom` is the right approach.

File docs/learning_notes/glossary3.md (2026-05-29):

# Embedded / Firmware Glossary

Terms encountered in the MCU #3 bringup sessions.

---

**APB clock** — Advanced Peripheral Bus clock. One of the internal clock sources on ESP32, running at 80MHz. Used by peripherals including UART. arduino-esp32 2.x derived UART baud rates from APB; 3.x switched to XTAL.

**Auto-baud detection** — a UART receiver feature that measures incoming bit timing to determine the sender's baud rate automatically. CP2102 does not have this — it must be configured to exactly match the sender.

**Baud rate** — the number of signal changes per second on a serial line. For UART, this equals bits per second. Sender and receiver must agree on the same value or framing errors corrupt the data.

**Baud rate derivation** — the process of dividing a clock source frequency down to produce a target baud rate. If the clock frequency doesn't divide evenly into the target baud, there is a residual deviation. Large deviation causes framing errors at the receiver.

**Bit-banging** — implementing a hardware protocol (I2C, SPI, UART) entirely in software by toggling GPIO pins manually, without using a hardware peripheral. Slower and CPU-intensive, but avoids peripheral conflicts. U8g2 SW_I2C uses bit-banging.

**CP2102** — Silicon Labs USB-to-UART bridge IC. Converts USB data from a PC to UART signal levels (3.3V/5V). Used on the ESP32-WROOM-32 DevKit as the programming and monitor interface. Has no auto-baud — baud rate must match exactly.

**ESP-IDF** — Espressif IoT Development Framework. The official C SDK for ESP32 chips. Provides drivers, FreeRTOS integration, peripheral APIs, and the build system. arduino-esp32 is a layer on top of IDF.

**FIFO** — First In, First Out. A hardware queue built into a peripheral (UART TX, I2C TX). Data written to the FIFO is transmitted in order. "Pre-loading the TX FIFO" means writing response bytes into it before the master requests them, so they are ready to transmit immediately.

**FreeRTOS** — a real-time operating system kernel. Provides tasks (threads), queues, semaphores, and mutexes. Already running under the Arduino layer on ESP32 — you do not start it manually.

**GPIO matrix** — a hardware routing table inside ESP32 that maps peripheral signals (I2C SDA, UART TX, etc.) to physical GPIO pins. Allows any peripheral to be routed to almost any pin. `gpio_reset_pin()` clears a pin's entry in this table.

**gpio_reset_pin()** — IDF function that resets a GPIO pin to its default (floating input) state and removes it from the GPIO matrix, making it available for reassignment.

**I2C_NUM_0 / I2C_NUM_1** — identifiers for the two hardware I2C peripheral instances on ESP32-WROOM-32. Each is an independent hardware block. ESP32-C3 has only one (I2C_NUM_0).

**IDF component manager** — Espressif's dependency management tool for IDF components (analogous to npm for Node.js). Downloads and caches components listed in `idf_component.yml`. Stores them in `managed_components/` — auto-generated, not committed to git.

**interrupt** — a hardware signal that causes the CPU to immediately suspend the current task and execute a designated handler function (ISR). Used for time-sensitive events like I2C data arrival. The CPU resumes the previous task after the ISR returns.

**ISR** — Interrupt Service Routine. The function that runs when an interrupt fires. Must be short and fast — blocking FreeRTOS calls are forbidden. Uses `FromISR` variants of semaphore/queue APIs.

**pioarduino** — a community fork of the PlatformIO espressif32 platform that bundles arduino-esp32 3.x (IDF 5.5.x). Used for MCU #3 because IDF 5.2+ is required for `i2c_new_slave_device()`.

**platform (PlatformIO)** — the PlatformIO concept that bundles a toolchain, framework, and board support package for a specific chip family. `espressif32@7.0.1` bundles IDF 4.4.7. pioarduino bundles IDF 5.5.x.

**portMAX_DELAY** — a FreeRTOS constant meaning "wait forever." Passed as the timeout to blocking calls like `xSemaphoreTake()` or `xQueueReceive()` when the task should block indefinitely until the resource is available.

**pull-up resistor** — a resistor connected between a signal line and VCC. I2C requires pull-ups on SDA and SCL because the bus is open-drain — devices can only pull lines low, never high. The pull-up provides the high state passively.

**ring buffer** (also: circular buffer) — a fixed-size array treated as wrap-around. A write pointer advances on each write; a read pointer advances on each read. When either reaches the end, it wraps to index 0. Allows continuous data flow without allocation or shifting.

**sdkconfig** — the full generated configuration file for an IDF build. Contains hundreds of `CONFIG_*` keys. Generated from `sdkconfig.defaults` by the build system — do not commit it. Commit only `sdkconfig.defaults`.

**sdkconfig.defaults** — a sparse file containing only the `CONFIG_*` keys you want to override from IDF defaults. The build system merges this with IDF's full default config to produce `sdkconfig`.

**semaphore** — a FreeRTOS synchronization primitive. A binary semaphore has two states: given and taken. Used here to signal between an ISR (gives the semaphore) and a task (takes/blocks on the semaphore). `xSemaphoreGiveFromISR()` is the ISR-safe variant.

**smoke test** — the most basic possible test that a system doesn't immediately fail. Origin: powering on a new circuit and checking it doesn't literally smoke. Does not test correctness — only confirms basic operation.

**TG1WDT** — Timer Group 1 hardware watchdog. Monitors that each core's idle task gets CPU time at least once per second. Fires if any idle task is starved. On dual-core WROOM, a priority-20 task on Core 1 starves IDLE1 and triggers TG1WDT.

**TwoWire** — the Arduino class wrapping the I2C peripheral. `Wire` is TwoWire instance 0, `Wire1` is instance 1. On ESP32-WROOM-32, both map to real hardware peripherals. arduino-esp32 3.x auto-initializes `Wire` on GPIO8/9 before `setup()` runs.

**UART** — Universal Asynchronous Receiver/Transmitter. A serial communication protocol using two wires (TX, RX). Asynchronous means no shared clock — both sides must be configured to the same baud rate independently.

**XTAL** — crystal oscillator. The external crystal providing the base clock reference on ESP32. Runs at 40MHz on most ESP32 boards. arduino-esp32 3.x switched UART clock source from APB to XTAL, causing baud rate deviation at 115200 with CP2102.

**xTaskCreate()** — FreeRTOS function to create a new task (thread). Arguments include: function pointer, name, stack size (bytes on ESP32), parameters pointer, priority, and handle pointer. The task starts running immediately after creation if its priority is high enough.

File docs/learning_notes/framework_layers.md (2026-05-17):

┌─────────────────────────────────────┐
│         Your Application            │  main.cpp, tasks, business logic
├─────────────────────────────────────┤
│       Arduino Framework             │  Wire, Serial, pinMode, setup/loop
├─────────────────────────────────────┤
│     ESP-IDF Components              │  driver/i2c, driver/uart, driver/gpio
├─────────────────────────────────────┤
│   FreeRTOS (ESP32 port)             │  tasks, queues, semaphores, timers
├─────────────────────────────────────┤
│   HAL (Hardware Abstraction Layer)  │  esp32-hal-i2c.c, esp32-hal-gpio.c
│   ESP-IDF                           │  chip-specific register wrappers
├─────────────────────────────────────┤
│   ESP32 Hardware Peripherals        │  I2C, GPIO matrix, UART, SPI, timers
│   (memory-mapped registers)         │
├─────────────────────────────────────┤
│         Silicon                     │  Xtensa LX6 cores, physical chip
└─────────────────────────────────────┘

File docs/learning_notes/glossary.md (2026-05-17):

## Glossary

**TG1WDT** — Timer Group 1 hardware watchdog. Monitors that each core's idle task gets CPU time at least once per second. Fires if any idle task is starved.

**Idle task (IDLE0/IDLE1)** — Lowest-priority FreeRTOS task, one per core. Runs only when no other task is ready. WDT monitors it as a health signal.

**loopTask** — Arduino's main task wrapping `setup()` and `loop()`. Runs on Core 1 on ESP32-WROOM-32.

**i2cSlaveInit()** — Internal Arduino Wire function that creates `i2c_slave_task` at priority 20 — higher than all user tasks — causing IDLE1 starvation on dual-core ESP32.

**Open-drain** — Electrical configuration where a device can only pull a wire LOW or release it. Wire goes HIGH passively via pull-up resistor. Fundamental to I2C — multiple devices share SDA safely.

**Pull-up resistor** — Resistor connecting a signal line to VCC. Biases the line HIGH when nothing actively drives it low. Required on I2C SDA and SCL lines.

**Pull-down resistor** — Resistor connecting a signal line to GND. Biases the line LOW when nothing drives it.

**Bit-banging** — Software simulation of a hardware protocol by manually toggling GPIO pins. U8g2 uses this for software I2C. CPU-intensive, no hardware offloading.

**Spin-loop (busy-wait)** — Code that repeatedly checks a condition without yielding. Example: waiting for UART TX FIFO space. Blocks the CPU entirely.

**UART TX FIFO** — Hardware queue for outgoing serial bytes. Limited size. `uart_write()` spin-loops when full, blocking the task.

**Hardware abstraction layer (HAL)** — Layer of code isolating hardware-specific details from application logic. Same interface, different implementations per chip.

**Bridge pattern** — Software design pattern separating abstraction from implementation so both can vary independently. Used here: same SharedBus interface, different WROOM/C3 implementations.

**Conditional compilation** — Using `#ifdef`/`#ifndef` preprocessor directives to include different code paths at compile time based on build flags (e.g. `MCU_BOARD_WROOM`).

**`esp_log_level_set()`** — ESP-IDF runtime function to set log verbosity per tag. `esp_log_level_set("gpio", ESP_LOG_WARN)` suppresses INFO messages from the GPIO driver.

**`i2c_driver_install()`** — IDF 4.4.7 I2C driver init function. Also creates internal tasks — same WDT problem as Arduino Wire on WROOM dual-core.

**`i2c_new_slave_device()`** — IDF 5.x+ new I2C slave API. Interrupt-driven, no internal task creation. Requires `framework = espidf` to access.

**TwoWire** — Arduino ESP32 class implementing I2C. `Wire` = `TwoWire(0)`, `Wire1` = `TwoWire(1)`. Pins assigned at `begin()` time.

**`sdkconfig.defaults`** — Minimal ESP-IDF project config overrides file. Source of truth. Auto-generates full `sdkconfig.esp32dev` at build time. Only custom lines go here.

**Combined framework mode** — `framework = arduino, espidf` in platformio.ini. Keeps Arduino APIs while exposing ESP-IDF internals. Still bundles IDF 4.4.7 with Arduino framework.

**Context save (`_xt_context_save`)** — Xtensa CPU routine saving registers during FreeRTOS task switch. Appearing in WDT backtrace indicates WDT fired during task creation/switching.

**`vTaskDelay()`** — FreeRTOS call that blocks a task for N ticks, removing it from the ready list. Allows idle task to run. Not the same as `vTaskYield()`.

**`vTaskYield()`** — FreeRTOS call that passes execution to the next ready task at same or higher priority. Does not guarantee idle task runs.

**Core affinity** — FreeRTOS concept of pinning a task to a specific CPU core via `xTaskCreatePinnedToCore()`. Default tasks use `tskNO_AFFINITY`.

**U8g2** — Display driver library supporting many OLED/LCD controllers. Handles SSD1306 protocol, font rendering, framebuffer. Supports both software and hardware I2C transport.

**Hardware I2C (U8g2)** — U8g2 mode using the ESP32 hardware I2C peripheral instead of bit-banging. Configured via `U8G2_SSD1306_128X64_NONAME_F_HW_I2C` constructor.

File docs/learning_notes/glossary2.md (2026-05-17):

# Glossary — Mainframe Simulation Project
*Accumulated from session: MCU #3 platform investigation and architecture design*

---

## Hardware & Chip Architecture

**ESP32-WROOM-32**
Dual-core ESP32 module (Xtensa LX6, Core 0 + Core 1). Has two hardware I2C
peripherals. GPIO8/9 available as general-purpose pins. Used for MCU #3.

**ESP32-C3 SuperMini**
Single-core RISC-V ESP32 variant. Has only one hardware I2C peripheral
(SOC_I2C_NUM=1). Used for MCUs #1, #2, #4, #5.

**Dual-core architecture**
CPU design with two independent processing cores. Each core runs its own
FreeRTOS scheduler instance and its own idle task. Relevant here because
a task monopolizing one core does not affect the other core — but does
starve that core's idle task independently.

**HAL (Hardware Abstraction Layer)**
Code layer sitting between a high-level API (e.g. Arduino's `Wire`) and
hardware-specific implementation (e.g. IDF's `i2c_driver_install()`).
Compiled against a specific IDF version — cannot be swapped independently
without recompiling the entire layer.

**GPIO matrix**
ESP32 internal routing layer that maps peripheral signals to physical GPIO
pins. Allows most peripherals to be assigned to most pins, unlike fixed-pin
designs.

**Open-drain**
Electrical configuration where a device can only pull a wire LOW or release
it. Wire goes HIGH passively via pull-up resistor. Fundamental to I2C —
multiple devices share SDA safely.

**Pull-up resistor**
Resistor connecting a signal line to VCC. Biases the line HIGH when nothing
actively drives it low. Required on I2C SDA and SCL lines.

**Pull-down resistor**
Resistor connecting a signal line to GND. Biases the line LOW when nothing
drives it.

---

## ESP-IDF & Framework

**ESP-IDF (Espressif IoT Development Framework)**
Native SDK for ESP32 chips. Provides drivers, FreeRTOS integration, and
hardware peripheral APIs. Version determines which APIs are available.

**IDF 4.4.7**
Bundled with arduino-esp32 core 2.x / PlatformIO espressif32@7.0.1.
`i2c_driver_install()` is the slave API. Does not have `i2c_new_slave_device()`.

**IDF 5.5.x**
Bundled with arduino-esp32 core 3.3.x / pioarduino stable.
Has `i2c_new_slave_device()` — interrupt-driven slave driver, no internal
task creation.

**Combined framework mode**
`framework = arduino, espidf` in platformio.ini. Keeps Arduino APIs while
exposing ESP-IDF internals. IDF version is locked to what the Arduino core
bundles — cannot be upgraded independently.

**`sdkconfig.defaults`**
Minimal ESP-IDF project config overrides file. Source of truth for build
configuration. Auto-generates full `sdkconfig` at build time. Only custom
lines go here — not the full generated config.

**`CONFIG_ARDUINO_RUNNING_CORE`**
sdkconfig key controlling which CPU core Arduino's `loopTask` is pinned to.
Default is Core 1. Was set to Core 0 experimentally during WDT investigation
— should be reverted to default.

**`CONFIG_AUTOSTART_ARDUINO`**
sdkconfig key required in combined framework mode. Tells IDF to start the
Arduino subsystem automatically on boot.

---

## I2C Driver

**`i2c_driver_install()`**
IDF 4.4.7 I2C driver init function. Used for both master and slave mode.
In slave mode, its internal behavior during initialization caused WDT on
WROOM — exact mechanism unconfirmed pending source code analysis.

**`i2c_new_slave_device()`**
IDF 5.2+ new I2C slave API. Interrupt-driven — registers an ISR that fires
only when the I2C peripheral receives data. Creates no internal FreeRTOS
task. Correct fix for the WDT problem. Available via `driver/i2c_slave.h`.

**`driver_ng`**
"Next generation" IDF I2C driver. The `ng` suffix indicates it is the
replacement for the legacy driver. `driver/i2c_slave.h` and `driver/i2c.h`
cannot coexist in the same build — including both causes a link error.

**`i2c_slave_task`**
Internal task name cited in community reports for the IDF 4.4 Arduino Wire
slave implementation. Claimed priority: 20. Unconfirmed from source code
— source grep found no `xTaskCreate` in IDF's `i2c.c`. May be in the
Arduino HAL layer instead. Requires further investigation next session.

**`i2cSlaveInit()`**
Internal Arduino Wire function that initializes I2C slave mode. Suspected
location of task creation causing WDT. Not yet confirmed from source code.

**`i2c_slave_read_buffer()`**
IDF 4.4.7 function to read received bytes from the I2C slave hardware FIFO.
Blocking with configurable timeout. Used in the test sketch's `loop()`.

**Hardware I2C (U8g2)**
U8g2 mode using the ESP32 hardware I2C peripheral instead of bit-banging.
Configured via `U8G2_SSD1306_128X64_NONAME_F_HW_I2C` constructor.

**Bit-banging**
Software simulation of a hardware protocol by manually toggling GPIO pins.
U8g2 uses this for software I2C. CPU-intensive — no hardware offloading.
On WROOM, caused WDT due to GPIO driver INFO log spam flooding UART TX FIFO.

**TwoWire**
Arduino ESP32 class implementing I2C. `Wire` = `TwoWire(0)`, `Wire1` =
`TwoWire(1)`. Pins assigned at `begin()` time.

---

## FreeRTOS Concepts

**FreeRTOS**
Real-Time Operating System running on ESP32. Provides tasks, queues,
semaphores, mutexes. Already running under Arduino — do not call
`vTaskStartScheduler()`.

**Task**
Independent unit of execution in FreeRTOS. Has its own stack, priority,
and state. Created with `xTaskCreate()` or `xTaskCreatePinnedToCore()`.

**Task states**
- **Running** — currently executing on a core
- **Ready** — eligible to run, waiting for CPU
- **Blocked** — waiting for an event (semaphore, queue, delay). Removed
  from ready list. CPU is freed for other tasks.
- **Suspended** — explicitly paused, not scheduled

**Blocking**
A task voluntarily removing itself from the ready list to wait for an event.
CPU is freed. Correct pattern for tasks waiting on I2C, UART, queues.
Opposite of busy-waiting.

**Busy-wait / spin-loop**
A task staying on the ready list while waiting, repeatedly checking a
condition without yielding. CPU is consumed even though no useful work is
done. Starves lower-priority tasks on the same core.

**Yielding**
A task voluntarily returning control to the scheduler. `vTaskYield()` moves
the task to the back of the ready list at its own priority — scheduler picks
highest priority ready task next. Does NOT guarantee lower-priority tasks run.
Distinct from blocking — the task stays in the ready list.

**`vTaskDelay()`**
FreeRTOS call that blocks a task for N ticks, removing it from the ready
list. Allows lower-priority tasks and idle task to run. Not the same as
`vTaskYield()`.

**`vTaskYield()`**
FreeRTOS call that passes execution to the next ready task at same or higher
priority. Does not guarantee idle task runs. Does not block the calling task.

**Preemption**
Scheduler forcibly interrupting a running task to switch to a higher-priority
ready task. Triggered by the FreeRTOS tick interrupt. Only switches to equal
or higher priority — cannot preempt to run a lower-priority task.

**Priority**
Integer value (0 = lowest) assigned to a task at creation. FreeRTOS always
runs the highest-priority ready task on each core. IDLE tasks are priority 0.

**Priority inheritance**
FreeRTOS mechanism for mutexes only: if a high-priority task waits for a
mutex held by a low-priority task, the low-priority task temporarily inherits
the higher priority to finish faster. Does NOT apply generally — FreeRTOS
has no general priority aging.

**Priority aging**
Algorithm where a repeatedly-skipped task's priority increases over time to
prevent permanent starvation. FreeRTOS does NOT implement this (outside of
mutex priority inheritance). Developer is responsible for not starving tasks.
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

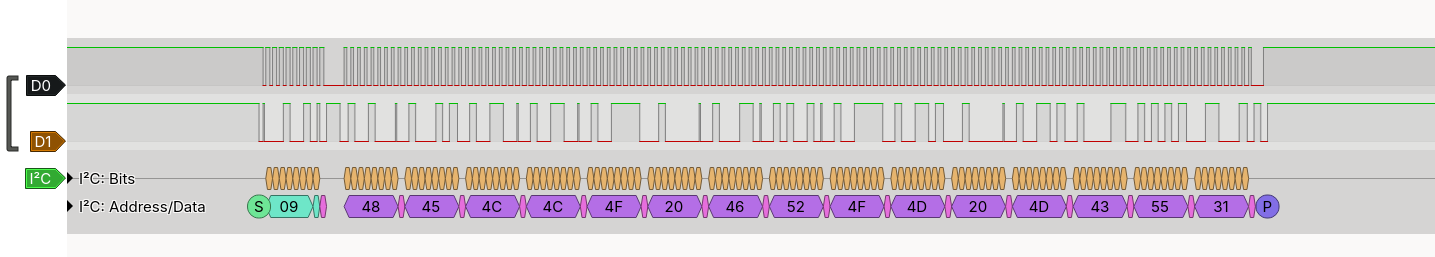
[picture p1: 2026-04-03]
docs/captures/task3_i2c_transmission_decoded.png.png

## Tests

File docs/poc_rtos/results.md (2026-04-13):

# PoC Results

**Date tested:** 2026-04-13
**Hardware:** MCU #1 (0x08) + MCU #2 (0x09) on shared bus
**Firmware commit:** 2bda77e3c3be0150158649a5ccb1035f20ed522f

---

## A1 — TwoWire mode switching

**Result:** PASS

**Cycles run:** 200+

**BUS_FAULT errors observed:** 0

**ACKs received on MCU #1:** matches MCU #2 RX count exactly (see A2)

**Notes:**

Occasional `NOT_FOUND` (BusError value 1) errors observed on both Sender A
and Sender B. These are clean I2C NACKs — not bus corruption. They occur when
MCU #2 is briefly in master mode sending a HEARTBEAT_ACK and cannot receive
the next incoming heartbeat during that window. This is expected half-duplex
I2C behavior, not a mode switching failure.

No `BUS_FAULT` errors observed at any point. Mode switching via `_bus.end()`
→ master init → transmit → slave reinit is stable across hundreds of cycles.

---

## A2 — FreeRTOS queue integrity

**Result:** PASS

**Total sends (MCU #1):** A: ~137 + B: ~92 = ~229 at time of reading
**Total receives (MCU #2):** ~240 (slightly ahead due to fast increment)
**Messages dropped:** 0
**QUEUE_FULL errors:** 0

**Notes:**

MCU #2 RX count tracks MCU #1 A+B send count exactly when read at the same
moment. The apparent small difference in the snapshot above is due to the
counts changing rapidly during manual copying — confirmed in sync on a second
reading.

MCU #1 ACK count also matches MCU #2 RX count exactly, confirming that every
message received by MCU #2 produced a successful ACK back to MCU #1. No
messages were dropped at any queue stage.

---

## A3 — Mutex protection

**Result:** PASS

**Validation failures on MCU #2:** 0

**PulseView overlapping transactions observed:** pending photo capture

**Notes:**

Zero `MessageProtocol::validate()` failures observed on MCU #2 across the
entire test run. Errors on MCU #1 appear as clean `NOT_FOUND` NACKs
alternating between Sender A and Sender B — never simultaneous, confirming
the mutex is correctly serializing bus access. No garbled JSON was produced.

---

## Overall result

**PASS — proceed to Phase 3**

**Unexpected findings:**

`vTaskStartScheduler()` must not be called explicitly on ESP32 Arduino — the
framework already starts FreeRTOS before `setup()` runs. Calling it a second
time crashes with `ESP_ERR_NOT_FOUND` on the systick interrupt allocation.
Fix: remove `vTaskStartScheduler()` from `setup()`. Tasks created with
`xTaskCreate()` start running immediately since the scheduler is already
active. Added `vTaskDelete(NULL)` in `loop()` to reclaim loopTask stack.

**Changes made during testing:**

- Removed `vTaskStartScheduler()` from both MCU #1 and MCU #2 `setup()`
- Added `vTaskDelete(NULL)` to `loop()` in both MCUs

---

## Captures

`docs/captures/poc_rtos_result.jpg` — MCU #1 OLED showing send counts and ACK count. MCU #2 OLED showing RX count and last message type.

---

## Next step

All three assumptions pass. Proceed to:

1. Update ADR-007 status to reflect PoC completion
2. Update roadmap — check off Phase 2.5 PoC items
3. Design full 5-MCU FreeRTOS task architecture
4. Redesign SharedBus for all five MCUs
5. Migrate MCUs #3, #4, #5 main.cpp to FreeRTOS task pattern

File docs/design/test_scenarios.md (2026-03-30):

# 🧪 Test Scenarios

Six concrete scenarios drive development and validation of the system.

---

## Scenario 1 — Simple Deposit

**Command:** `DEPOSIT 12345678 100.00`

**Goal:** Verify basic transaction flow end-to-end — from I/O Controller through Transaction Processor to Database Controller and back.

**Learning focus:** Message routing, data validation, persistent storage.

---

## Scenario 2 — Insufficient Funds

**Command:** `WITHDRAW 87654321 100.00`

**Goal:** Demonstrate error handling when account balance is insufficient.

**Learning focus:** Business logic validation, error propagation across subsystems.

---

## Scenario 3 — Account Transfer

**Command:** `TRANSFER 12345678 87654321 50.00`

**Goal:** Multi-account atomic transaction — debit one account and credit another as a single indivisible operation.

**Learning focus:** Transaction atomicity, locking mechanisms.

---

## Scenario 4 — Priority Scheduling

**Goal:** Submit jobs at different priority levels and observe HIGH priority jobs preempting LOW priority queue entries.

**Learning focus:** Priority scheduling algorithms, queue management.

---

## Scenario 5 — Load Test

**Command:** `LOADTEST 50`

**Goal:** Submit 50 rapid transactions and observe system behaviour under load.

**Learning focus:** System bottlenecks, message queueing, performance characteristics.

---

## Scenario 6 — Subsystem Failure

**Setup:** Physically disconnect the Database Controller during operation.

**Goal:** Observe how the system handles a missing subsystem — timeouts, error propagation, health monitoring.

**Learning focus:** Failure modes, timeout handling, health monitoring.

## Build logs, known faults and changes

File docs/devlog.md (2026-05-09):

# Devlog

---

## Phase 1.5 — SharedBus Class: Encapsulation and ISR-Safe Receive
*Goal: extract shared bus boilerplate into a shared library; fix ISR-unsafe OLED calls in onReceive*

### What we built
- `SharedBus` class in `shared/libs/shared_bus/` — encapsulates TwoWire(0) entirely
- `beginMaster()` / `beginSlave(address)` replace raw TwoWire init in every main.cpp
- `BusError send(target, message)` wraps the 3-step TwoWire dance with a typed error return
- `poll(buf, len)` replaces the `onReceive` callback pattern — safe to call from `loop()`
- No raw `TwoWire`, `Wire.h`, or pin numbers remain in any main.cpp

### Design decisions

**BusError enum over bool**
`endTransmission()` returns 5 distinct codes. A bool collapses `NOT_FOUND`, `BUS_FAULT`,
and `TIMEOUT` into a single failure, making diagnostics harder. `BusError` preserves the
distinction so callers can log or display the specific failure reason.

**poll() over onReceive callback**
The original MCU #2 code called `oled.showStatus()` directly inside `onReceive`. That
callback runs in interrupt context — calling U8g2 software I2C (bit-banging GPIOs) from
inside an active I2C interrupt is a known deadlock/corruption risk on ESP32.
The fix: `onReceive` ISR only reads raw bytes into an internal `_rxBuf` (no I2C, no heap,
no blocking). `poll()` is called from `loop()` — safe for OLED updates, Serial, and
anything else. The cost is a small polling delay (~10ms) which is acceptable for this
use case.

**Static _instance pointer**
Arduino's `onReceive` requires a plain C function pointer — no lambdas, no member
function pointers. A static `_instance` pointer lets the static ISR reach the live
TwoWire and buffer. One SharedBus per MCU is the intended constraint.

### Verified pass criteria
- MCU #1 serial: `[MCU1] SEND OK — MCU2 acknowledged` ✅
- MCU #2 serial: `[MCU2] Received: HELLO FROM MCU1` ✅
- No raw TwoWire or pin numbers in either main.cpp ✅
- shared_bus picked up automatically by PlatformIO LDF via lib_extra_dirs ✅

### Key learnings
- `endTransmission()` return codes map cleanly to typed errors — worth modelling explicitly
- ISR callbacks on Arduino are not safe for I2C or any blocking operation; buffer-and-poll
  is the standard workaround
- Static singleton pattern is the only practical way to bridge C-style callbacks to C++ objects
  in the Arduino framework

---

## Phase 1.5 — Dual I2C Bus Fix: OLED + Shared Bus Simultaneously
*Goal: run OLED display and inter-MCU shared bus at the same time on each MCU*

### What we built
- Migrated OLED library from Adafruit SSD1306 (hardware I2C) to U8g2 (software I2C)
- Both MCU #1 (master) and MCU #2 (slave) now run OLED and shared bus simultaneously
- U8g2 bit-bangs I2C in software on GPIO3/GPIO10, leaving TwoWire(0) free for shared bus

### What went wrong and how it was fixed

**1. TwoWire(1) silently fails on ESP32-C3**
Initial approach was to assign OLED to TwoWire(1) and shared bus to TwoWire(0).
Both MCUs crashed at boot with repeated `[Wire.cpp:526] write(): NULL TX buffer pointer`.
Root cause: ESP32-C3 has `SOC_I2C_NUM = 1` — only one hardware I2C peripheral.
`TwoWire(1).begin()` calls `i2cInit(1, ...)` which returns `ESP_ERR_INVALID_ARG` since
`1 >= SOC_I2C_NUM`. The buffer is never allocated. No error is surfaced to Arduino code.
The comment in soc_caps.h even says "have 2 I2C" — the comment is wrong.

**2. SoftWire not compatible with Adafruit SSD1306**
SoftWire was the first candidate to replace TwoWire(1). Rejected because
`Adafruit_SSD1306` takes a `TwoWire*` in its constructor — SoftWire doesn't
inherit from TwoWire, so it can't be passed where `TwoWire*` is expected without
modifying the Adafruit library.

**3. U8g2 SW_I2C constructor argument order**
U8g2 software I2C constructor takes `(rotation, SCL, SDA, reset)` — SCL before SDA,
opposite of Wire convention. Passing them in Wire order (SDA, SCL) would silently
communicate on the wrong pins.

**4. ISR constraint on MCU #2**
`onReceive` fires in interrupt context. Calling `oled.showStatus()` from inside it
would trigger I2C writes during an active I2C interrupt — a known deadlock/corruption
scenario on ESP32. OLED updates were kept in the receive handler in the current code
and remain a known risk; to be addressed when SharedBus class is introduced.

### Verified pass criteria
- MCU #1 serial: `[OLED] PASS: initialized` + `[MCU1] SEND OK — MCU2 acknowledged` ✅
- MCU #2 serial: `[OLED] PASS: initialized` + `[MCU2] Received 15 bytes: HELLO FROM MCU1` ✅
- Both running simultaneously without conflict ✅

### Key learnings
- ESP32-C3 `SOC_I2C_NUM = 1`: only one hardware I2C peripheral, despite misleading comment
- `TwoWire(1)` constructs silently but fails at `begin()` — no Arduino-level error
- For multi-bus I2C on ESP32-C3: hardware bus for shared/critical path, U8g2 SW_I2C for display
- Adafruit SSD1306 is not compatible with software I2C drop-ins — it requires `TwoWire*`
- U8g2 y-coordinates are text baseline, not top-left corner

---

## Task 3 — I2C Communication: MCU #1 (Master) → MCU #2 (Slave)
*Goal: establish verified bidirectional I2C communication on shared bus (GPIO8/GPIO9)*

### What we built
- Shared inter-MCU I2C bus: GPIO8=SDA, GPIO9=SCL, 5kΩ pull-ups to 3.3V
- MCU #1 as I2C master: sends "HELLO FROM MCU1" to address 0x09 every 2 seconds
- MCU #2 as I2C slave: listens on 0x09, prints received bytes to serial
- Config architecture: shared_config.h (pins + addresses) + per-MCU config.h

### What went wrong and how it was fixed

**1. Bench supply USB-C confusion**
Bench supply (Wanptek WPS3010H) output is off by default — must press output
button to enable. Current display shows 0.000A for low-draw devices which looks
like "not powered" but isn't. Red LED on MCU confirmed power delivery was fine.

**2. Shared config header not found by compiler**
Added ../shared/config to lib_extra_dirs in platformio.ini — but PlatformIO's
LDF only scans lib_extra_dirs for libraries with library.json, not plain headers.
Fix: use build_flags = -I ../shared/config instead. This passes the path directly
to the compiler.

**3. Accidentally flashed master code onto MCU #2**
Both MCUs ended up running identical master code. Neither was acting as slave,
so no ACK was ever possible. Lesson: always check main.cpp contents before
flashing, not just which directory you're in.

**4. TwoWire.begin() wrong overload for slave mode**
Slave code called: sharedBus.begin(I2C_ADDRESS, SHARED_SDA_PIN, SHARED_SCL_PIN)
This silently hit the wrong overload — the 3-argument form doesn't exist for
slave mode. The correct 4-argument slave overload requires explicit frequency:
    sharedBus.begin(I2C_ADDRESS, SHARED_SDA_PIN, SHARED_SCL_PIN, 0)
Without the 0, pins were ignored and slave never responded. Caught by reading
the actual TwoWire source — not trusting examples blindly.

**5. Logic analyzer SCL/SDA swapped in PulseView decoder**
Physical connections: D0=SDA (GPIO8/blue), D1=SCL (GPIO9/orange)
PulseView I2C decoder default assigns channel0=SCL, channel1=SDA — opposite
of our wiring. With wrong assignment, decoder showed Address: 0x00 instead of
0x09 and couldn't find stop condition. Fix: manually assign SCL→D1, SDA→D0
in decoder channel settings.

**6. Logic analyzer disconnecting mid-capture**
Short USB cable + unstable header connection caused intermittent disconnects,
producing flat-line captures that looked like idle bus. Fix: secure the header
connection, use a longer USB cable with slack.

### Verified pass criteria
- MCU #1 serial: [MCU1] SEND OK — MCU2 acknowledged ✅
- MCU #2 serial: [MCU2] Received 15 bytes: HELLO FROM MCU1 ✅
- PulseView decode: S | 09 | 48 45 4C 4C 4F 20 46 52 4F 4D 20 4D 43 55 31 | P ✅
  (translates to: HELLO FROM MCU1)

### Key learnings
- Read actual library source signatures — don't trust examples or docs alone
- endTransmission() return code 2 = address NACK = slave not responding,
  not a bus wiring problem
- TwoWire(0) constructor + explicit pins is mandatory on ESP32-C3 for
  non-default I2C pins — Wire.begin() has a confirmed bug
- OSI model applies to embedded I2C just like networking:
  Layer 1 = wires/pull-ups, Layer 2 = I2C protocol, Layer 7 = your message format
- PulseView SCL/SDA assignment must match physical wiring — wrong assignment
  produces plausible-looking but incorrect decode

### Captures
- docs/captures/task3_i2c_transmission_decoded.png
- docs/captures/task3_pulseview_session.sr

---

---

## Phase 2 Prep — Physical Layout Planning
*Goal: plan final breadboard arrangement before soldering MCU #3, #4, #5*

### What we decided

T-shape layout on 30×30cm wood base:
- Vertical long BB (spine): MCU #3 (top) + shared bus hub (bottom)
- Horizontal long BB (base): MCU #4 (left) + MCU #5 (right)
- Short BB left: MCU #1
- Short BB right: MCU #2

Hub at the T-junction gives approximately equal wire length to all five MCUs.
All shared bus wires (SDA/SCL/GND) run directly from each MCU to hub rails.
OLED wires stay local — they never reach the hub.

Wire color convention established:
- Orange = SDA (GPIO8)
- White/grey = SCL (GPIO9)
- Black = GND
- Blue = OLED SDA (GPIO3, local only)
- Light blue = OLED SCL (GPIO10, local only)

### Wiring diagram
- docs/diagrams/bb_full.fzz (Fritzing)
- docs/captures/ — SVG layout diagrams

### Physical fixing
Double-sided foam tape or velcro strips recommended over hot glue — allows
individual boards to be lifted for rework. Hot glue only after all wiring verified.

---

## Phase 2 Prep — System Design Documentation
*Goal: write formal design documents before implementing Phase 2*

### What we wrote

**docs/requirements.md**
Formal functional (FR-01–FR-12) and non-functional (NFR-01–NFR-06) requirements.
Key decisions:
- FR-05 (crash recovery) and FR-10 (atomic transfer) deferred to Phase 5
- NFR-02 reworded: "50 sequential transactions without dropping any" —
  I2C is physically sequential, "concurrent" was misleading
- FR-11: MCU #5 web console for submitting transactions
- FR-12: BALANCE enquiry as a first-class transaction type

**docs/design/system_design.md**
Full architecture document covering subsystem map, communication topology,
data flows for all transaction types, data model, error handling, and open questions.

**docs/design/message_protocol.md**
Complete JSON message format specification for all 11 message types:
JOB_SUBMIT, JOB_DISPATCH, JOB_COMPLETE, JOB_RESULT, DB_READ, DB_READ_RESULT,
DB_WRITE, DB_WRITE_ACK, HEARTBEAT, HEARTBEAT_ACK, ERROR.

**docs/decisions/ — Architecture Decision Records**
- ADR-001: I2C as inter-MCU protocol
- ADR-002: U8g2 software I2C for OLED
- ADR-003: SharedBus poll() pattern
- ADR-004: I2C buffer expanded to 256 bytes
- ADR-005: JSON message format with ArduinoJson
- ADR-006: Balance display on both OLED and web console

**docs/captures/ — Sequence diagrams**
SVG sequence diagrams for all four flows:
- Deposit transaction (happy path)
- Insufficient funds (rejection path)
- Balance enquiry (read-only path)
- Heartbeat with subsystem failure detection

### Key design decisions

**Money as integer cents**
All monetary values stored and transmitted as uint32_t cents.
$100.00 = 10000. Float arithmetic is never used for money — a standard rule
in financial software. Formatting to $x.xx is done at display layer only.

**Job ID as composite: (senderAddr << 8) | sequenceNum**
UUID rejected — 36 chars consumes 14% of 256 byte message budget for no benefit
since MCU #5 is the only job source (no collision possible). Composite uint16_t
gives uniqueness across MCUs if multiple sources are added later, costs 2 bytes.

**BALANCE as a txnType, not a special case**
Balance enquiry follows the same job flow as DEPOSIT/WITHDRAW but skips DB_WRITE.
Priority LOW. Result returned in JOB_COMPLETE payload and displayed on both
MCU #5 OLED and web console (ADR-006).

**Job lifecycle: QUEUED → DISPATCHED → COMPLETE/FAILED**
MCU #4 tracks job state explicitly. JOB_COMPLETE from MCU #2 carries jobId so
MCU #4 can match and remove the correct queue entry. Timeout + retry once before
marking FAILED and alerting MCU #1.

**Dual-file storage on MCU #3**
Two separate SD card files:
- accounts.json — current balances (written on every transaction)
- transactions.log — append-only audit log (written first, before accounts update)
Write-ahead log pattern: log entry written before balance update. On boot,
MCU #3 can detect and replay incomplete transactions. (Phase 5 feature.)

### Open questions (recorded in system_design.md)
- MCU #5 web console design — HTML form structure
- WiFi + I2C simultaneous stability on ESP32-C3 (risk: timing interference)
- Runtime account creation via MCU #1 serial console (Phase 3)
- Maximum job queue depth before MCU #4 rejects new submissions
- Two-phase commit design for TRANSFER (Phase 5)

---

## Phase 2 Prep — Tooling: Git Hook for CLAUDE.md Memory Sync
*Goal: automatically extract and sync key facts when CLAUDE.md files change*

### What we built
- `scripts/claude_memory_sync.py` — post-commit hook
- Triggers only when CLAUDE.md files are modified in the commit
- Calls Claude API to summarize changed sections into memory-sized facts
- Attempts to write facts to Anthropic memory API

### What worked
- Change detection: correctly identifies modified CLAUDE.md files via git diff
- Summarization: Claude API call correctly extracts key facts from diffs
- Credits issue resolved: Anthropic API requires prepaid credits even with valid key

### What didn't work
- Memory write API: `memory-2025-01-01` beta header is invalid
- Correct header is `context-management-2025-06-27` but the memory tool
  uses a tool-call pattern (not a simple write endpoint) — more complex than
  a one-liner fix
- Memory write step currently fails silently after summarization succeeds

### Current state
Hook fires and summarizes correctly. Memory write is disabled pending a
proper implementation of the context-management tool-call pattern.
CLAUDE.md files in git remain the primary context source for Claude Code.

### Key learnings
- Anthropic memory API is tool-based (agent makes tool calls, app handles them locally)
  not a simple REST write endpoint
- `lib_extra_dirs` in PlatformIO only finds libraries with library.json —
  plain header files need `-I path` in build_flags instead

---

## Phase 2 — Full 5-MCU Shared Bus + Message Protocol
*Goal: all five MCUs communicating over shared I2C bus with structured JSON messages*

### What we built
- MessageProtocol shared library: `shared/libs/message_protocol/`
  - UUID v4 job IDs via ESP32 hardware RNG (`esp_random()`)
  - Short wire-format keys (`"ac"`, `"am"`, `"tp"`) to save I2C budget
  - Integer codes for MsgType, TxnType, Status, Priority — uint8_t on wire
  - Runtime schema validation — strict, rejects on any missing field
  - Debug name helpers (`msgTypeName`, `statusName` etc.) for serial output
  - `API_REFERENCE.md` documents every method, field, and constant
- All 5 MCUs wired to shared bus hub on vertical long BB
- MCU #1 verified communicating with each slave individually (sequential pair tests)

### Key design decisions

**UUID v4 for jobId**
Composite ID (senderAddr << 8 | seq) rejected in favour of UUID v4.
Reason: 64GB SD card means billions of transactions in the log over project
lifetime. uint16_t wraps at 65,535. UUID v4 via esp_random() costs 36 bytes
on the wire but short field keys freed that budget entirely.

**Integer codes for message types and status**
MsgType, TxnType, Status, Priority are all uint8_t on the wire.
Saves ~8 bytes per message vs full strings. Constants remain human-readable
in code (MsgType::JOB_SUBMIT) — debug name helpers convert back to strings
for serial output only. Never use name helper return values in logic.

**Short field name keys**
Field names shortened ("msgId"→"mid", "account"→"ac" etc.).
Freed ~35 bytes per message — enough to accommodate 36-byte UUID job IDs
with headroom remaining in the 256-byte I2C buffer.

**ArduinoJson v7 API fix**
`createNestedObject()` deprecated in v7.
Replacement: `doc[Field::PAYLOAD].to<JsonObject>()`
Caught by VSCode Claude during integration review.

**Money as integer cents**
All `amount`, `balance`, `newBalance` fields are uint32_t cents.
$100.00 = 10000. Float arithmetic never used for money.
Formatting to $x.xx done at display layer only.

### Verified pass criteria
- MCU #1 → MCU #2: send + ACK confirmed ✅
- MCU #1 → MCU #3: send + ACK confirmed ✅
- MCU #1 → MCU #4: send + ACK confirmed ✅
- MCU #1 → MCU #5: send + ACK confirmed ✅
- All tested as sequential pairs — full 5-MCU simultaneous bus test pending ⏳
- All 5 OLEDs active during respective pair tests ✅

### Physical setup complete
- T-shape layout on 30×30cm wood base
- Vertical long BB (spine): MCU #3 (top) + shared bus hub (bottom)
- Horizontal long BB (base): MCU #4 (left) + MCU #5 (right)
- Short BB left: MCU #1 · Short BB right: MCU #2
- Each MCU's 3.3V and GND pins connected to breadboard + and - rails
- Two 5kΩ pull-ups on hub: one on SDA line, one on SCL line
- Logic analyzer probes on hub for PulseView verification

### Next step (Phase 3 prerequisite)
Connect all 5 MCUs to hub simultaneously and run full bus test before
implementing any subsystem logic. This is a different test from pair testing —
verifies signal quality, pull-up strength, and bus arbitration with all
devices present.

---

## Phase 2.5 — Architecture Pivot: FreeRTOS
*Goal: identify why Arduino loop() is insufficient and plan FreeRTOS migration*

### What we discovered

Full 5-MCU heartbeat test revealed two separate problems:

**1. Slaves cannot send — Bus is in Slave Mode**
MCU #2 correctly received HEARTBEAT from MCU #1 but sendAck() failed:
`[Wire.cpp:411] beginTransmission(): Bus is in Slave Mode`
Root cause: TwoWire on ESP32-C3 is master OR slave per boot. Once beginSlave()
is called, beginTransmission() is rejected by the driver. This is not a bug —
it is the intended Wire API behaviour.

**2. Truncated messages — IncompleteInput**
MCU #4 received messages but MessageProtocol::parse() reported IncompleteInput.
Root cause: SharedBus _rxBuf was 32 bytes — smaller than HEARTBEAT messages.
Fix: increase _rxBuf to 256 bytes (matching I2C_BUFFER_LENGTH build flag).

**3. I2C_BUFFER_LENGTH=256 missing from some platformio.ini files**
Not all MCUs had the build flag. Added to all five.

### Why this matters architecturally

The slave-cannot-send constraint means MCU #4 (JES) cannot talk directly to
MCU #3 (DASD) unless it switches to master mode. In Arduino loop() this is
fragile — there is no safe window to reconfigure because the slave must listen
continuously. In FreeRTOS, a dedicated sender task can acquire a mutex, switch
to master, send, switch back, release mutex — safely, because the listener task
continues running independently.

### Decision

Adopt FreeRTOS tasks for all MCUs. See ADR-007 for full reasoning.

The pivot is not a failure of Phase 1–2. Those phases confirmed the hardware
works, validated the shared libraries, and revealed exactly why the constraint
exists. You cannot know FreeRTOS is the right choice without first hitting the
multi-master wall. The foundation built in Phases 1–2 is unchanged and reused.

### What stays the same
- All 5 MCU roles, addresses, and physical layout
- OledDisplay, SharedBus (to be extended), MessageProtocol libraries
- shared_config.h, per-MCU config.h, platformio.ini structure
- All ADRs 001–006 remain valid

### What changes
- SharedBus: add mutex, runtime mode switching (beginMaster/beginSlave at any time)
- Each MCU main.cpp: loop() replaced by FreeRTOS task creation
- Communication: any MCU can initiate — MCU #1 is monitor/logger, not proxy

### Verified so far
- MCU #1 sends HEARTBEAT to all 4 slaves simultaneously ✅
- MCU #3 (0x0A) and MCU #4 (0x0B) receive correctly ✅
- MCU #2 (0x09) receives but cannot ACK — Bus is in Slave Mode ✅ (confirms constraint)
- MCU #5 (0x0C) wiring issue — not yet receiving (to be resolved)
- _rxBuf[256] fix resolves IncompleteInput on MCU #4 ✅

### Next steps
1. Validate FreeRTOS multi-master I2C proof of concept (2 MCUs)
2. Redesign SharedBus for task-safe operation
3. Redesign each MCU as FreeRTOS tasks
4. Full 5-MCU simultaneous bus test with new architecture

---

## Phase 2.5 — FreeRTOS PoC: Multi-Master I2C Validation
*Goal: validate three assumptions before migrating all five MCUs to FreeRTOS*

### Context

Phase 2 testing revealed that TwoWire on ESP32-C3 locks into master or slave
mode at boot. A slave cannot initiate transmissions, meaning MCU #4 (JES)
cannot send directly to MCU #3 (DASD) without routing through MCU #1. This
distorts the mainframe architecture. ADR-007 documents the pivot to FreeRTOS
tasks with mutex-protected bus access so any MCU can temporarily become master,
transmit, then return to slave.

Before migrating all five MCUs, three assumptions had to be validated on real
hardware using MCU #1 and MCU #2 only.

### What we built

- `SharedBus` refactored: `beginMaster()` / `beginSlave()` replaced by
  `init(address)`. Internally: `busMutex` protects all bus access,
  `_rxSemaphore` replaces `volatile bool _rxReady`, ISR now calls
  `xSemaphoreGiveFromISR()` to wake the receiver task instantly instead of
  relying on polling.
- `send()` internally switches master → transmit → slave while holding
  `busMutex`. Any task on the same MCU can call it safely.
- `poll()` blocks the receiver task on `_rxSemaphore` — zero CPU consumed
  while waiting. Wakes instantly when the ISR fires.
- MCU #1 `main.cpp`: four FreeRTOS tasks — Sender A (2s), Sender B (3s),
  Receiver (pri=3), Logic, OLED (pri=1). Two sender tasks at different
  intervals deliberately collide to stress-test the mutex.
- MCU #2 `main.cpp`: three FreeRTOS tasks — Receiver (pri=3), Logic, OLED.
  Logic task validates every received message and sends HEARTBEAT_ACK.
- Separate `displayMutex` on both MCUs protects display state struct from
  partial reads by the OLED task during context switches.
- Stack size constants added to `shared_config.h` (bytes, not words):
  `STACK_SIZE_SENDER` / `STACK_SIZE_LOGIC` = 4096,
  `STACK_SIZE_RECEIVER` / `STACK_SIZE_OLED` = 2048.

### Critical fix: do not call vTaskStartScheduler() on ESP32 Arduino

The first flash crashed immediately after tasks were created:

```
func: vPortSetupTimer
expression: esp_intr_alloc(ETS_SYSTIMER_TARGET0_EDGE_INTR_SOURCE ...)
ESP_ERR_NOT_FOUND
abort() was called
```

Root cause: ESP32 Arduino starts FreeRTOS automatically before `setup()` is
called. `setup()` and `loop()` themselves run inside a FreeRTOS task called
`loopTask`. Calling `vTaskStartScheduler()` explicitly tried to start the
scheduler a second time, which attempted to re-allocate the systick interrupt
— already taken — and crashed.

Fix: remove `vTaskStartScheduler()` entirely. Tasks created with `xTaskCreate()`
start running immediately because the scheduler is already active. Added
`vTaskDelete(NULL)` in `loop()` to delete `loopTask` and reclaim its stack
(~8KB) once `setup()` returns.

```cpp
// setup(): just create tasks and return
xTaskCreate(senderTaskA, "SenderA", STACK_SIZE_SENDER, NULL, 2, NULL);
// ... other tasks ...
// no vTaskStartScheduler() call

void loop() {
    vTaskDelete(NULL); // delete loopTask, reclaim stack
}
```

### Verified pass criteria

All three assumptions passed. See `docs/poc/results.md` for full details.

| Assumption | Result | Evidence |
|---|---|---|
| A1 — mode switching | PASS | No BUS_FAULT across 300+ cycles |
| A2 — queue integrity | PASS | MCU #2 RX = MCU #1 A+B sends exactly |
| A3 — mutex protection | PASS | Zero validation failures on MCU #2 |

Occasional `NOT_FOUND` (BusError value 1) errors observed on both senders.
These are clean I2C NACKs occurring when MCU #2 is briefly in master mode
sending a HEARTBEAT_ACK and temporarily cannot receive. This is expected
half-duplex behavior — not a mode switching failure or mutex bug. The full
architecture will handle this with retry logic already defined in the message
protocol.

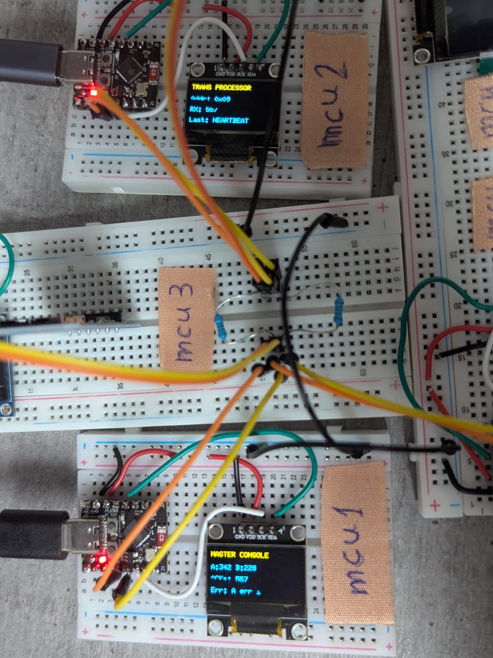
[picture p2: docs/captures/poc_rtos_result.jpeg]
PoC result — MCU #1 and MCU #2 OLEDs running


MCU #1 OLED shows send counts for both Sender A and B incrementing
independently, ACK count tracking in sync with MCU #2 RX count.
MCU #2 OLED shows RX incrementing with Last: HEARTBEAT — clean receive
throughout the test run.

### Key learnings

- On ESP32 Arduino, FreeRTOS is already running when `setup()` is called.
  Never call `vTaskStartScheduler()` — it crashes with `ESP_ERR_NOT_FOUND`.
- ISR to task signaling via `xSemaphoreGiveFromISR()` + `portYIELD_FROM_ISR()`
  is the correct FreeRTOS pattern. The receiver task wakes in the same tick
  as the ISR returns if it has higher priority than the running task.
- A separate `displayMutex` for display state is important. The `busMutex`
  can be held for tens of milliseconds during a full send cycle — an OLED
  task waiting on it would produce visible display lag.
- Stack size units on ESP32 `xTaskCreate()` are bytes, not words (unlike
  vanilla FreeRTOS). 4096 bytes for tasks using ArduinoJson + Serial,
  2048 bytes for shallow tasks (receiver, OLED).
- `volatile` does not replace a mutex for multi-field structs. A context
  switch mid-write leaves the struct in a partially updated state that
  `volatile` cannot prevent.

### Next steps

Phase 2.5 complete. Proceed to:
1. Update ADR-007 status
2. Update roadmap Phase 2.5 checklist
3. Design full 5-MCU FreeRTOS task architecture
4. Migrate SharedBus and main.cpp for MCUs #3, #4, #5

---

## Phase 3 Start — 5-MCU FreeRTOS Validated + MCU #1 Heartbeat & Health Monitoring
*Goal: migrate all MCUs to FreeRTOS task pattern and confirm full 5-MCU simultaneous bus operation*

### What we built

**MCUs #3, #4, #5 migrated to FreeRTOS**
Each follows the same scaffold pattern: Receiver (pri=3), Logic (pri=2), OLED (pri=1).
Logic task handles HEARTBEAT → HEARTBEAT_ACK for now. Subsystem-specific logic
(DB_READ/DB_WRITE, JOB_DISPATCH, HTTP server) to follow in Phase 3 continuation.

**Full 5-MCU simultaneous bus test confirmed**
All five MCUs running concurrently on the shared I2C bus. MCU #1 sends HEARTBEAT
to all four slaves sequentially; all four respond with HEARTBEAT_ACK. OLEDs blinking
on all five boards simultaneously. This is the first time the full system has run
as intended.

**MCU #1: heartbeat task + timestamp-based health monitoring**
Replaced Phase 2.5 dual-sender PoC with a single Heartbeat task. Key design change:
moved from a per-cycle `activeSubsystems` counter to per-slave `lastAckTime[4]`
timestamps. Active count is computed at display time by comparing each timestamp
against `HEARTBEAT_ACK_TIMEOUT_MS` (30s).

### Why the counter approach caused OLED flicker

The original design stored `activeSubsystems` as a shared field written by two tasks:
- `heartbeatTask` reset it to 0 at the start of each cycle
- `logicTask` incremented it on each ACK

The OLED task ran on a 500ms timer independent of the heartbeat cycle (10s). Any time
the OLED task snapshotted `displayState` between the reset and the last ACK arriving,
it would briefly display "Act:0/4" or a partial count — visible as a flicker on the
display every 10 seconds.

### The fix: timestamps instead of a running counter

```cpp
struct SharedState {
    uint32_t lastAckTime[4];  // millis() written by logicTask on each ACK
    uint32_t heartbeatCount;
    char     lastError[24];
};
```

`heartbeatTask` no longer touches the active count at all. `logicTask` writes
`millis()` to `lastAckTime[slaveIndex(from)]` on each ACK. `oledTask` computes
the active count locally from the snapshot — a slave is active if its `lastAckTime`
is non-zero and within `HEARTBEAT_ACK_TIMEOUT_MS`. Nothing resets between cycles.
No partial state is ever visible.

The same computation is used in `serialInputTask`'s STATUS handler for consistency.

### Key constants added to shared_config.h
```cpp
#define HEARTBEAT_INTERVAL_MS    10000   // interval between heartbeat cycles
#define HEARTBEAT_ACK_TIMEOUT_MS 30000   // slave inactive after 3× interval
```

### Verified pass criteria
- All 5 MCUs receiving heartbeats and ACKing ✅
- MCU #1 OLED Act:4/4 stable — no flicker ✅
- HEARTBEAT_ACK_TIMEOUT_MS causes a slave to drop to Act:3/4 if unplugged ✅ (by design)
- Full 5-MCU simultaneous bus operation confirmed on real hardware ✅

### Key learnings
- A shared counter written by two tasks at different phases of a cycle is inherently
  racy with a periodic reader — even with mutex protection. Timestamps solve this
  cleanly: each writer is independent, the reader always computes from a consistent snapshot.
- The 10s heartbeat interval means a slave timeout of 30s (3×) gives two missed
  heartbeats before flagging — enough margin for occasional bus errors without
  false positives.

---

## 2026-04-16 — Phase 3: FreeRTOS migration, SD card debugging, ESP32 DevKit substitution

### What was attempted

Phase 3 migration of MCUs #3, #4, #5 from Arduino loop() to FreeRTOS task
pattern, followed by SD card integration on MCU #3.

---

### FreeRTOS migration (MCUs #3, #4, #5)

All three MCUs migrated from old `sharedBus.beginSlave()` pattern to the
FreeRTOS `sharedBus.init()` API. The shared `receiverTask` function was
extracted into the `shared_bus` library to avoid duplication — the task body
is identical on all MCUs, taking a `ReceiverParams*` via `xTaskCreate` params.

A `static ReceiverParams` is declared at file scope in each MCU's `main.cpp`
with a comment warning against moving it into `setup()` — the task holds a
pointer to this struct, so it must outlive `setup()`.

MCU #1 was simultaneously updated from PoC form (SenderA/SenderB mutex stress
test) to Phase 3 form: single Heartbeat task sending to all 4 slaves
sequentially every 10 seconds, SerialInput task, Logic task.

**5-MCU simultaneous bus test result:** MCUs #3 and #4 received heartbeats
immediately. MCUs #2 and #5 were silent — OLED showing RX:0.

**Root cause:** The shared bus hub used pull-up resistors as physical bridges
between the two breadboard halves. Resistors are unidirectional pull-up
devices, not wire bridges — 5kΩ in series on the signal path meant MCU #2 and
#5 (on the far side of the hub) never saw clean I2C logic levels.

**Fix:** Replaced resistors-as-bridges with plain jumper wires. All 5 MCUs
immediately began receiving heartbeats and sending ACKs. Act:4/4 on MCU #1 OLED.

**OLED flickering bug:** MCU #1 OLED showed Act:2/4 and Act:1/4 intermittently
despite all 4 slaves ACKing cleanly (confirmed in serial monitor). Root cause:
`heartbeatTask` reset `activeSubsystems` to 0 at cycle start, then `logicTask`
incremented it as ACKs arrived over 2 seconds. OLED task snapshotted partial
counts mid-cycle.

**Fix:** Replaced `activeSubsystems` counter with `lastAckTime[4]` array.
Each slave's last ACK timestamp is recorded in milliseconds. `oledTask`
computes active count at display time by counting entries fresher than
`HEARTBEAT_ACK_TIMEOUT_MS` (30 seconds = 3× heartbeat interval). Count only
updates when a slave genuinely goes silent — never flickers mid-cycle.
`HEARTBEAT_INTERVAL_MS` and `HEARTBEAT_ACK_TIMEOUT_MS` added to `shared_config.h`.

`DisplayState` renamed to `SharedState` throughout MCU #1 — more accurate name
since the struct is shared between multiple tasks, not just display data.

---

### SD card integration — ESP32-C3 SuperMini pin exhaustion

Attempted to add SPI SD card to MCU #3 (ESP32-C3 SuperMini). Wired to
GPIO6=SCK, GPIO7=MOSI, GPIO2=MISO, GPIO4=CS.

All attempts failed with SdFat error 0x17 (CMD0 — card never responded) and
crashes in `spiTransferByteNL`. Tried SdFat and SD.h libraries, FAT32 and
exFAT formats, multiple pin combinations, two different SD modules.

SPI loopback test (MOSI jumpered to MISO) passed — confirming SPI hardware
works. The problem is pin-level.

Investigation confirmed: GPIO6/7 are internal flash SPI pins (reserved in all
modes). GPIO4–7 are JTAG reserved. GPIO0/2 are strapping pins. After
subtracting shared bus (GPIO8/9) and OLED (GPIO3/10), there are not enough
clean GPIOs for 4 SPI signals on the ESP32-C3 SuperMini.

**Resolution:** Replaced MCU #3 ESP32-C3 SuperMini with an ESP32 DevKit
(ESP32-D0WDQ6, 38-pin) from the parts stash. Headers soldered, board
recognized on /dev/ttyUSB0 via CH340C. New SPI pin mapping:
GPIO19=MISO, GPIO23=MOSI, GPIO18=SCK, GPIO5=CS. OLED moved to GPIO16/17.

**Consequence for shared_config.h:** `OLED_SDA_PIN` and `OLED_SCL_PIN` moved
from `shared_config.h` to per-MCU `config.h` since they are no longer universal.
MCUs #1/#2/#4/#5 keep GPIO3/10. MCU #3 uses GPIO16/17.

SD card formatted: FAT32, 8GB partition on 64GB physical card (FAT32 volumes
over 32GB are unreliable with Arduino SD libraries — remainder left unallocated).

SD init test not yet run on new board — carried over to next session.

---

### Key learnings

- **Resistors are not wire bridges.** Pull-up resistors have resistance — using
  them as physical connectors between breadboard halves puts 5kΩ in series on
  the I2C signal path, corrupting signals for MCUs on the far side.

- **ESP32-C3 SuperMini GPIO budget is extremely tight.** 11 exposed pins minus
  strapping pins, JTAG pins, and flash SPI pins leaves very few truly free GPIOs.
  Running shared I2C bus + OLED + SPI simultaneously is not feasible.

- **"Newer and smaller" is not always better.** The ESP32 classic (2016) has
  more free GPIOs than the ESP32-C3 SuperMini (2020) for general-purpose use.
  The C3 was designed for single-purpose IoT nodes, not multi-peripheral projects.

- **SPI loopback test is the correct first step** for isolating SD card issues.
  It confirms SPI hardware works before suspecting the SD module or card.

- **SD card size matters for library compatibility.** Cards over 32GB formatted
  as FAT32 are out of spec. SdFat with exFAT on ESP32 is unstable. Use a ≤32GB
  card or create a ≤8GB FAT32 partition.

- **Daisy chain GND** across all breadboards is essential. Missing common ground
  causes I2C devices to appear deaf even when SDA/SCL are correctly wired.

---

### Documentation updated this session

- ADR-008: ESP32 DevKit replaces ESP32-C3 SuperMini for MCU #3
- shared_config.h: OLED pins removed (moved to per-MCU config.h)
- config.h: all 5 MCUs updated with local OLED pin definitions
- MCU #3 platformio.ini: board=esp32dev, port=/dev/ttyUSB0
- MCU #3 CLAUDE.md: hardware change, new pins, Phase 3 implementation steps
- roadmap.md: Phase 3 reordered by dependency, Phase 5 RAID-1 added

---

### SD card integration — WeMos LOLIN32 Lite GPIO8/9 unavailability

Previous session ended with ESP32 DevKit (first replacement for MCU #3)
unresolved. Board was actually a WeMos LOLIN32 Lite clone (ESP32-D0WDQ6,
CH340C) — listing was misleading.

Attempted SD card init test on LOLIN32 Lite with SdFat library.
Wiring: GPIO19=MISO, GPIO23=MOSI, GPIO18=SCK, GPIO5=CS.

Failures observed across multiple sessions:
- SdFat error 0x17 (CMD0 — card not responding) — intermittent
- SdFat error 0x0C (CMD8 — voltage check failed) — after MOSI/MISO swap
- SdFat error 0x01 (CMD1 timeout) — after breadboard bypass with direct jumpers

Debugging steps taken:
- Verified continuity on all 6 SD module wires
- Bypassed breadboard entirely with direct dupont jumpers — eliminated
  contact noise, errors became consistent
- Tried SD.h and SdFat libraries, multiple card formats (partitioned FAT32,
  raw FAT32 full device)
- Removed FreeRTOS and SharedBus entirely from test sketch — isolated SD
  test to bare minimum (OLED + SD only)
- Confirmed crystal anomaly: esptool reports 41.36MHz vs expected 40MHz —
  explains junk Serial output before app starts, cosmetic only

Root cause identified: **GPIO8 and GPIO9 are not available on the LOLIN32
Lite.** Per the board pinout, these pins are connected to the 32kHz crystal
oscillator (Xtal32N/Xtal32P) — they are internal and not broken out for
user GPIO. The shared inter-MCU I2C bus requires GPIO8=SDA and GPIO9=SCL
on all MCUs. This makes the LOLIN32 Lite fundamentally incompatible with
the project's shared bus architecture, regardless of the SD card outcome.

**Resolution:** Ordered ESP32-WROOM-32 DevKit (38-pin, CP2102, Type-C USB).
This board has GPIO8/9 available as user GPIO, confirmed via official pinout.
VSPI pins (18/19/23/5) are clean for SD card. All pin assignments from
config.h remain unchanged — only the physical board changes.

Also ordered:
- ESP32 Terminal Adapter (screw terminals) — eliminates breadboard contact
  failures that caused intermittent SD errors throughout this session
- Second SD card module (identical) — for Phase 5 RAID-1 implementation

Waiting for delivery. No firmware changes required on arrival — main.cpp,
config.h, and platformio.ini are all correct for esp32dev target.

---

### Key learnings

- **GPIO8/9 are crystal pins on LOLIN32 Lite** — not available for user I2C.
  Always verify GPIO8/9 availability on any ESP32 board before ordering for
  this project. The shared bus depends on them across all MCUs.

- **Breadboard contact failures are insidious.** Errors were inconsistent and
  changed with every reboot — classic intermittent contact symptom. Direct
  jumper wiring immediately gave consistent error codes, enabling real
  diagnosis. Terminal adapters eliminate this class of problem entirely.

- **Crystal frequency deviation on clones causes Serial junk.** The 41.36MHz
  vs 40MHz crystal on the LOLIN32 Lite clone produces garbled boot ROM output.
  App Serial output is clean after calibration. Cosmetic only, not a bug.

- **SdFat error codes are diagnostic.** 0x17=CMD0 (no response), 0x0C=CMD8
  (voltage check), 0x01=CMD1 (legacy init timeout). Progression from 0x17
  toward 0x01 indicates improving signal quality — useful for isolating
  wiring vs. firmware vs. formatting issues.

- **"ESP32 DevKit" AliExpress listings are unreliable.** The board received
  was a LOLIN32 Lite clone despite "DevKit" in the listing. Always verify
  the module silkscreen and pinout before assuming GPIO availability.

---

### Documentation updated this session

- ADR-008: LOLIN32 Lite failure documented, ESP32-WROOM-32 DevKit selected
- MCU #3 CLAUDE.md: board updated to ESP32-WROOM-32 DevKit 38-pin
- Project CLAUDE.md: hardware table updated
- devlog: this entry

## 2026-05-07 — Phase 3: SD card final debugging on ESP32-WROOM-32 DevKit, architecture pivot to RPi UART backend

*Goal: confirm SD card init on new ESP32-WROOM-32 DevKit, proceed to FreeRTOS skeleton*

---

### SD card debugging — ESP32-WROOM-32 DevKit

Previous session ended with ESP32-WROOM-32 DevKit (38-pin, CP2102) ordered
and on the way — third board for MCU #3 slot. Board arrived confirmed genuine:
module silkscreen reads ESP-32D (ESP32-D0WDQ6), HW-395 V0.03, Type-C USB,
pins pre-soldered. Terminal adapter also arrived. Board recognized immediately
on /dev/ttyUSB0 via CP2102. Stable port ID:
`usb-Silicon_Labs_CP2102_USB_to_UART_Bridge_Controller_0001-if00-port0`

SD card reformatted from FAT32 to exFAT to match `SdExFat`/`ExFile` types
already in main.cpp. Two firmware fixes applied before first flash:

1. `SdSpiConfig` was missing `&SPI` as fourth argument — SdFat could fall
   back to a default SPI instance not initialized with our pin assignments.
2. `SD_CARD_TYPE_SD1/SD2/SDHC` constants are from SD.h and do not exist in
   SdFat 2.x — compile error. Replaced switch block with uint8_t ternary.

First flash: OLED initialized correctly. SD init failed with error 0x17
(CMD0 — card not responding at all).

**Debugging sequence:**

Verified `SPI.begin()` executes (added Serial print). Confirmed CS reads 3.3V
at idle (correct). Probed SCK during test — reads 0V. Added 5-second delay
after `SPI.begin()` to probe during init window — SCK still 0V. This initially
suggested SPI clock not being driven, but later reasoning clarified: 0V on SCK
is the idle state; the actual transmission window is too brief for a multimeter
to catch. The probe reading was not evidence of a fault.

Traced wiring color-by-color against terminal adapter labels. All six SD module
wires confirmed in correct terminals: white(MOSI)→P23, blue(MISO)→P19,
orange(SCK)→P18, green(CS)→P5, red(VCC)→3.3V rail, black(GND)→GND.

Error codes were varying between resets: 0x17 (CMD0), 0x0C (CMD8), 0x01
(CMD1) — the classic symptom of intermittent connection. Pressing blue wire
(MISO, P19) during reset made errors worse and more variable. Tightened P19
screw terminal — errors stabilized to consistent 0x0C.

Tried swapping MOSI/MISO (previous sessions confirmed this sometimes helps):
swapped config gave 0x0C consistently, correct config gave 0x17. This is
opposite of the previous session's result. The SD module's MOSI/MISO labels
appear to be from the card's perspective rather than the host's on this module.
Kept swapped configuration (0x0C is further in init than 0x17).

With stable wiring, error settled to 0x0C (CMD8 — voltage check) with
`data=0xFF`. The 0xFF data byte means MISO is reading all-ones — idle/floating
state. The card is not driving any response to CMD8.

Probed MOSI at the SD module during test — reads 0V. However: CMD0 passes
(0x0C means past CMD0), so MOSI must have been working during CMD0. The 0V
probe reading is a post-test static measurement, not evidence of a fault
during transmission.

CMD8 failure with data=0xFF and no progression despite stable wiring
across multiple resets. Multiple library configurations, card formats,
and pin combinations have been exhausted across three boards.

---

### Decision: architecture pivot

After three board replacements spanning several weeks and systematic
exhaustion of wiring, library, and firmware causes, the conclusion is
that the SD card path has an unacceptable reliability cost.

The failure modes seen across all boards are consistent:
- ESP32-C3 SuperMini: GPIO budget exhaustion (silicon constraint)
- WeMos LOLIN32 Lite clone: GPIO8/9 tied to crystal (board constraint)
- ESP32-WROOM-32 DevKit: CMD8 failure, MISO not driven (init/card constraint)

The third failure is particularly frustrating because it is past the
hardware-level problems that caused the first two. CMD0 passes, meaning
the SPI link is functional. But CMD8 fails consistently with data=0xFF,
suggesting the SDXC card and SdFat's init sequence have an incompatibility
that has not been resolved despite extensive debugging.

Continuing is not the right call. The DB controller is on the critical path
for Phase 3 — MCU #2 cannot process transactions without it, MCU #4 and MCU
#5 cannot be meaningfully tested, and end-to-end flows are blocked. A month
of debugging time has already been spent on storage alone.

**New approach: MCU #3 stays on shared I2C bus at 0x0A. All storage is
delegated to a Raspberry Pi 3B+ connected over UART.**

MCU #3 receives DB_READ and DB_WRITE from the shared bus exactly as designed.
Instead of hitting an SD card, it forwards the request to RPi over UART1
(GPIO18=TX, GPIO19=RX) using newline-terminated JSON. RPi responds, MCU #3
returns the result on the bus. No other MCU is affected — they still talk
to address 0x0A and receive the same message types.

RPi runs:
- `db_server.py` — UART listener, SQLite read/write, write-ahead log pattern
- `web_server.py` — Flask transaction history interface
- Cron rsync to dev PC — periodic SQLite backup over WiFi

This satisfies all original requirements: unbounded transaction history,
UUID transaction IDs, web interface, write-ahead log for crash recovery.
It also resolves the storage problem completely without any SPI wiring.

UART at 115200 baud gives ~10ms per round trip on a point-to-point link.
Total estimated transaction latency including all I2C hops and two UART
round trips: ~10–12 transactions per second sequential. Acceptable for
this simulation's purposes.

---

### Pin changes for MCU #3

Former SD card pins GPIO18/19 are now UART1. GPIO23 and GPIO5 are freed.

| Function | GPIO | Before | After |
|---|---|---|---|
| UART TX (to RPi) | GPIO18 | SD SCK | UART1 TX |
| UART RX (from RPi) | GPIO19 | SD MISO | UART1 RX |
| — | GPIO23 | SD MOSI | unconnected |
| — | GPIO5 | SD CS | unconnected |

Shared bus (GPIO8/9) and OLED (GPIO16/17) unchanged.

---

### Key learnings

- **Consistent error codes are diagnostic progress, not failure.** Moving
  from varying 0x17/0x0C/0x01 to stable 0x0C by tightening one screw
  terminal was real progress — it eliminated contact noise as a variable
  and isolated the failure to a specific init stage.

- **0xFF on data byte means MISO is floating.** When the card does not
  drive a response, MISO reads all-ones. This is distinct from a wiring
  fault — MISO is connected, but the card is not asserting anything.

- **Multimeter voltage probing during fast SPI is unreliable.** A multimeter
  averages over time. SCK toggling at 1MHz during a brief init burst will
  read somewhere between 0V and 3.3V, or 0V if the burst has already ended.
  It does not confirm or deny whether SPI is active.

- **Architectural pivots are sometimes the right call.** The SD card approach
  had legitimate reasons behind it — low cost, no extra hardware, self-contained.
  But the accumulated evidence across three boards and multiple sessions pointed
  to a consistent incompatibility that was not going to be resolved by more
  debugging. Cutting losses and redesigning around reliable components
  (RPi + UART) is the correct engineering response.

- **UART is simpler and more reliable than SPI for point-to-point links.**
  No chip select, no clock polarity/phase configuration, no library-level
  init sequence. Two wires and newline framing. The perceived complexity
  of "adding a Raspberry Pi" is offset by eliminating an entire class of
  hardware debugging.

---

### Documentation updated this session

- ADR-008: amended — SD card approach superseded, points to ADR-009
- ADR-009: new — UART/RPi architecture decision, protocol, repo structure
- MCU #3 CLAUDE.md: rewritten — UART task replaces SD task, new pin table,
  new Phase 3 implementation steps with clear DoD per step
- raspi-db-server/CLAUDE.md: new — RPi setup, UART protocol, SQLite schema,
  Flask, rsync, step-by-step DoD
- roadmap.md: Phase 3 MCU #3 items rewritten around RPi steps, Phase 5
  RAID-1 SD item replaced with SQLite rsync redundancy
- devlog: this entry

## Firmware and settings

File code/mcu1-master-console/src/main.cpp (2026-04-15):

#include <Arduino.h>
#include <freertos/FreeRTOS.h>
#include <freertos/task.h>
#include <freertos/queue.h>
#include <freertos/semphr.h>
#include "config.h"
#include "oled_display.h"
#include "shared_bus.h"
#include "message_protocol.h"

// ─────────────────────────────────────────────────────────────────────────────
// Globals
// ─────────────────────────────────────────────────────────────────────────────
OledDisplay oled(OLED_SDA_PIN, OLED_SCL_PIN);
SharedBus   sharedBus;

// inboundQueue: receiver task → logic task  (8 slots × 256 bytes)
QueueHandle_t inboundQueue;

// serialQueue: serialInput task → logic task  (4 slots × 64 bytes)
QueueHandle_t serialQueue;

// Shared state — written by heartbeat + logic tasks, read by OLED task.
// Protected by displayMutex to prevent the OLED task reading a half-updated
// struct during a context switch.
struct SharedState {
    uint32_t lastAckTime[4];  // indexed by slave order: 0=0x09, 1=0x0A, 2=0x0B, 3=0x0C
    uint32_t heartbeatCount;
    char     lastError[24];
};
static SharedState       sharedState = {{0, 0, 0, 0}, 0, "none"};
static SemaphoreHandle_t displayMutex;

// Static: must outlive setup(). Do NOT move inside setup() — task holds a pointer to this.
static ReceiverParams receiverParams;

// ─────────────────────────────────────────────────────────────────────────────
// Task: Heartbeat  (priority 2, STACK_SIZE_SENDER)
//
// Sends HEARTBEAT sequentially to all 4 slave MCUs every HEARTBEAT_INTERVAL_MS.
// ─────────────────────────────────────────────────────────────────────────────
void heartbeatTask(void* params) {
    uint32_t count = 0;
    char     buf[256];

    const uint8_t targets[] = {
        ADDR_TRANSACTION_PROCESSOR,
        ADDR_DATABASE_CONTROLLER,
        ADDR_JOB_SCHEDULER,
        ADDR_IO_CONTROLLER
    };

    while (true) {
        count++;

        for (uint8_t i = 0; i < 4; i++) {
            uint8_t target = targets[i];

            JsonDocument doc = MessageProtocol::createEnvelope(
                I2C_ADDRESS, target, MsgType::HEARTBEAT
            );
            doc[Field::PAYLOAD][Field::TIMESTAMP] = millis();

            if (!MessageProtocol::serialize(doc, buf, sizeof(buf))) {
                Serial.printf("[MCU1-HB] HEARTBEAT → 0x%02X: serialize failed (#%lu)\n",
                    target, count);
                continue;
            }

            BusError err = sharedBus.send(target, buf);
            Serial.printf("[MCU1-HB] HEARTBEAT → 0x%02X: %s (#%lu)\n",
                target,
                err == BusError::OK ? "OK" : "FAILED",
                count);

            // Give the slave 500ms to process and ACK before we switch to
            // master again for the next send. Without this, MCU #1 re-enters
            // master mode before the ACK arrives and the slave sees address
            // 0x08 as absent on the bus.
            vTaskDelay(pdMS_TO_TICKS(500));
        }

        xSemaphoreTake(displayMutex, portMAX_DELAY);
        sharedState.heartbeatCount = count;
        xSemaphoreGive(displayMutex);

        vTaskDelay(pdMS_TO_TICKS(HEARTBEAT_INTERVAL_MS));
    }
}

// ─────────────────────────────────────────────────────────────────────────────
// Task: Serial Input  (priority 2, STACK_SIZE_LOGIC)
//
// Reads newline-terminated commands from USB serial monitor.
// STATUS is handled immediately (reads sharedState under mutex).
// All other valid commands are forwarded to serialQueue for logicTask.
// ─────────────────────────────────────────────────────────────────────────────
void serialInputTask(void* params) {
    while (true) {
        if (!Serial.available()) {
            vTaskDelay(pdMS_TO_TICKS(50));
            continue;
        }

        String line = Serial.readStringUntil('\n');
        line.trim();

        if (line.length() == 0) continue;

        if (line.startsWith("STATUS")) {
            xSemaphoreTake(displayMutex, portMAX_DELAY);
            SharedState snap = sharedState;
            xSemaphoreGive(displayMutex);

            uint32_t now    = millis();
            uint8_t  active = 0;
            for (int i = 0; i < 4; i++) {
                if (snap.lastAckTime[i] > 0 &&
                    (now - snap.lastAckTime[i]) < HEARTBEAT_ACK_TIMEOUT_MS) {
                    active++;
                }
            }
            Serial.printf("[MCU1-SER] STATUS: activeSubsystems=%d/4, heartbeatCount=%lu\n",
                active, snap.heartbeatCount);
            continue;
        }

        // Validate known commands before queuing.
        bool known = line.startsWith("DEPOSIT ")
                  || line.startsWith("WITHDRAW ")
                  || line.startsWith("BALANCE ");

        if (!known) {
            Serial.printf("[MCU1-SER] unknown command: %s\n", line.c_str());
            continue;
        }

        // Put raw trimmed command string on serialQueue (64-byte slot).
        char cmdBuf[64];
        strncpy(cmdBuf, line.c_str(), sizeof(cmdBuf) - 1);
        cmdBuf[sizeof(cmdBuf) - 1] = '\0';

        if (xQueueSend(serialQueue, cmdBuf, 0) != pdTRUE) {
            Serial.println("[MCU1-SER] serialQueue full — command dropped");
        }
    }
}

// Returns the lastAckTime index for a given slave address.
// Returns -1 if address is not a known slave.
static int8_t slaveIndex(uint8_t addr) {
    switch (addr) {
        case ADDR_TRANSACTION_PROCESSOR: return 0;
        case ADDR_DATABASE_CONTROLLER:   return 1;
        case ADDR_JOB_SCHEDULER:         return 2;
        case ADDR_IO_CONTROLLER:         return 3;
        default:                         return -1;
    }
}

// ─────────────────────────────────────────────────────────────────────────────
// Task: Logic  (priority 2, STACK_SIZE_LOGIC)
//
// Drains inboundQueue (blocking) and serialQueue (non-blocking poll after each
// inbound message). Handles ACKs, errors, and serial commands.
// ─────────────────────────────────────────────────────────────────────────────
void logicTask(void* params) {
    char     buf[256];
    char     cmdBuf[64];
    uint32_t ackCount = 0;

    while (true) {
        // Block until receiver task puts something on inboundQueue.
        if (xQueueReceive(inboundQueue, buf, portMAX_DELAY) == pdTRUE) {
            JsonDocument     doc = MessageProtocol::parse(buf);
            ValidationResult res = MessageProtocol::validate(doc);

            if (!res.valid) {
                Serial.printf("[MCU1-LG] invalid message: %s\n", res.detail);

                xSemaphoreTake(displayMutex, portMAX_DELAY);
                snprintf(sharedState.lastError, sizeof(sharedState.lastError),
                    "%s", res.detail);
                xSemaphoreGive(displayMutex);
            } else {
                uint8_t type = doc[Field::TYPE];
                uint8_t from = doc[Field::FROM];

                switch (type) {
                    case MsgType::HEARTBEAT_ACK: {
                        ackCount++;
                        Serial.printf("[MCU1-LG] received HEARTBEAT_ACK from 0x%02X (#%lu)\n",
                            from, ackCount);

                        int8_t idx = slaveIndex(from);
                        if (idx >= 0) {
                            xSemaphoreTake(displayMutex, portMAX_DELAY);
                            sharedState.lastAckTime[idx] = millis();
                            xSemaphoreGive(displayMutex);
                        }
                        break;
                    }

                    case MsgType::ERROR: {
                        Serial.printf("[MCU1-LG] ERROR from 0x%02X\n", from);

                        xSemaphoreTake(displayMutex, portMAX_DELAY);
                        snprintf(sharedState.lastError, sizeof(sharedState.lastError),
                            "ERR from 0x%02X", from);
                        xSemaphoreGive(displayMutex);
                        break;
                    }

                    default:
                        Serial.printf("[MCU1-LG] unhandled type: %d from 0x%02X\n",
                            type, from);
                        break;
                }
            }
        }

        // Drain any pending serial commands (non-blocking).
        while (xQueueReceive(serialQueue, cmdBuf, 0) == pdTRUE) {
            // Phase 3 stub — actual dispatch to MCU #4 comes in Phase 4.
            Serial.printf("[MCU1-LG] serial cmd (stub): %s\n", cmdBuf);
        }
    }
}

// ─────────────────────────────────────────────────────────────────────────────
// Task: OLED  (priority 1 — lowest)
//
// Snapshots sharedState under displayMutex every 500ms, then updates display.
// ─────────────────────────────────────────────────────────────────────────────
void oledTask(void* params) {
    char line2[20], line3[20];

    while (true) {
        SharedState snap;
        xSemaphoreTake(displayMutex, portMAX_DELAY);
        snap = sharedState;
        xSemaphoreGive(displayMutex);

        // Compute active subsystem count from last ACK timestamps.
        // A slave is active if it ACKed within HEARTBEAT_ACK_TIMEOUT_MS.
        uint32_t now    = millis();
        uint8_t  active = 0;
        for (int i = 0; i < 4; i++) {
            if (snap.lastAckTime[i] > 0 &&
                (now - snap.lastAckTime[i]) < HEARTBEAT_ACK_TIMEOUT_MS) {
                active++;
            }
        }

        snprintf(line2, sizeof(line2), "HB:%lu Act:%d/4",
            snap.heartbeatCount, active);
        snprintf(line3, sizeof(line3), "Err:%s", snap.lastError);

        oled.showStatus("MASTER CONSOLE", line2, line3, "");

        vTaskDelay(pdMS_TO_TICKS(500));
    }
}

// ─────────────────────────────────────────────────────────────────────────────
// setup
// ─────────────────────────────────────────────────────────────────────────────
void setup() {
    Serial.begin(115200);
    delay(1000);
    Serial.println("[MCU1] Master Console starting — Phase 3");

    if (!oled.begin()) {
        Serial.println("[MCU1] OLED failed");
    }
    oled.showStatus("MASTER CONSOLE", "Starting...", "", "");

    // init() creates busMutex and rxSemaphore, then calls _switchToSlave().
    // Must happen before xTaskCreate() so semaphores exist before ISR fires.
    sharedBus.init(I2C_ADDRESS);

    displayMutex = xSemaphoreCreateMutex();
    if (displayMutex == nullptr) {
        Serial.println("[MCU1] FATAL: displayMutex failed");
        return;
    }

    inboundQueue = xQueueCreate(8, sizeof(char[256]));
    if (inboundQueue == nullptr) {
        Serial.println("[MCU1] FATAL: inboundQueue failed");
        return;
    }

    serialQueue = xQueueCreate(4, sizeof(char[64]));
    if (serialQueue == nullptr) {
        Serial.println("[MCU1] FATAL: serialQueue failed");
        return;
    }

    receiverParams = { &sharedBus, inboundQueue };

    xTaskCreate(receiverTask,    "Receiver",  STACK_SIZE_RECEIVER, &receiverParams, 3, NULL);
    xTaskCreate(heartbeatTask,   "Heartbeat", STACK_SIZE_SENDER,   NULL,            2, NULL);
    xTaskCreate(serialInputTask, "SerialIn",  STACK_SIZE_LOGIC,    NULL,            2, NULL);
    xTaskCreate(logicTask,       "Logic",     STACK_SIZE_LOGIC,    NULL,            2, NULL);
    xTaskCreate(oledTask,        "OLED",      STACK_SIZE_OLED,     NULL,            1, NULL);

    Serial.println("[MCU1] Tasks created — scheduler already running");
}

void loop() {
    vTaskDelete(NULL);
}

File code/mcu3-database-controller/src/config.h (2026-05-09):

// ─────────────────────────────────────────────────────────────────────────────
// MCU #3 — Database Controller
// File: code/mcu3-database-controller/src/config.h
// Board: ESP32-WROOM-32 DevKit (38-pin, CP2102) — see ADR-008, ADR-009
// ─────────────────────────────────────────────────────────────────────────────
#pragma once
#include "shared_config.h"

#define I2C_ADDRESS     ADDR_DATABASE_CONTROLLER

// OLED private bus (U8g2 software I2C)
#define OLED_SDA_PIN    16
#define OLED_SCL_PIN    17

// UART1 — connection to Raspberry Pi DB backend (see ADR-009)
// RPi GPIO14 (TX) → MCU GPIO19 (RX)
// RPi GPIO15 (RX) → MCU GPIO18 (TX)
#define UART_TX_PIN     18
#define UART_RX_PIN     19

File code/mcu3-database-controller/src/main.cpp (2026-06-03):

// ─────────────────────────────────────────────────────────────────────────────
// MCU #3 — Database Controller
// Phase 3.1 — i2c_new_slave_device() init, slave at 0x0A on GPIO8/9
//
// DoD:
//   3.1 No "GPIO 8/9 is not usable" warning in log
//       No WDT reset
//       "I2C slave init OK — addr 0x0A on GPIO8/9" in log
//       "on_receive callback registered" in log
//
// UART handshake + echo (Phase 1) commented out — preserved for Phase 5
// reintegration. Do not delete.
//
// Platform: espressif32 @ 6.10.0 (IDF 5.4), framework = espidf
// Board:    ESP32-WROOM-32 DevKit (38-pin, CP2102)
// ─────────────────────────────────────────────────────────────────────────────

#include "freertos/FreeRTOS.h"
#include "freertos/task.h"
#include "freertos/semphr.h"
#include "esp_log.h"
#include "esp_idf_version.h"
#include "driver/uart.h"
#include "driver/gpio.h"

#include "oled_display_wroom.h"
#include "shared_bus_wroom.h"
#include "shared_state.h"
#include "config.h"
#include <cstring>
#include <cstdio>

static const char* TAG = "MCU3";

// ── SharedState + mutex — definitions ────────────────────────────────────────
SharedState       gSharedState  = {};
SemaphoreHandle_t gDisplayMutex = nullptr;

// ── Shared bus ────────────────────────────────────────────────────────────────
static SharedBusWroom sharedBus;

// ═════════════════════════════════════════════════════════════════════════════
// UART — Phase 1 (commented out, preserved for Phase 5 reintegration)
// ═════════════════════════════════════════════════════════════════════════════

// #define UART_PORT            UART_NUM_1
// #define UART_BAUD            115200
// #define UART_RX_BUF          256
// #define UART_ECHO_TIMEOUT_MS 2000
//
// static void uart_init(void)
// {
//     const uart_config_t cfg = {
//         .baud_rate  = UART_BAUD,
//         .data_bits  = UART_DATA_8_BITS,
//         .parity     = UART_PARITY_DISABLE,
//         .stop_bits  = UART_STOP_BITS_1,
//         .flow_ctrl  = UART_HW_FLOWCTRL_DISABLE,
//         .source_clk = UART_SCLK_DEFAULT,
//     };
//     ESP_ERROR_CHECK(uart_param_config(UART_PORT, &cfg));
//     ESP_ERROR_CHECK(uart_set_pin(UART_PORT, UART_TX_PIN, UART_RX_PIN,
//                                  UART_PIN_NO_CHANGE, UART_PIN_NO_CHANGE));
//     ESP_ERROR_CHECK(uart_driver_install(UART_PORT, UART_RX_BUF, 0, 0, NULL, 0));
//     ESP_LOGI(TAG, "UART1 init OK — TX GPIO%d RX GPIO%d @ %d baud",
//              UART_TX_PIN, UART_RX_PIN, UART_BAUD);
// }
//
// static bool uart_read_line(char* buf, int buf_len, uint32_t timeout_ms)
// {
//     int pos = 0;
//     uint32_t remaining_ms = timeout_ms;
//     while (remaining_ms > 0) {
//         TickType_t t0 = xTaskGetTickCount();
//         uint8_t c;
//         int n = uart_read_bytes(UART_PORT, &c, 1, pdMS_TO_TICKS(remaining_ms));
//         TickType_t elapsed_ms = (xTaskGetTickCount() - t0) * portTICK_PERIOD_MS;
//         remaining_ms = (elapsed_ms >= remaining_ms) ? 0 : remaining_ms - elapsed_ms;
//         if (n == 1) {
//             if (c == '\n') { buf[pos] = '\0'; return true; }
//             if (c != '\r' && pos < buf_len - 1) buf[pos++] = (char)c;
//         }
//     }
//     buf[pos] = '\0';
//     return false;
// }
//
// static void uart_handshake(void)
// {
//     ESP_LOGI(TAG, "UART handshake — waiting for PING from RPi...");
//     char buf[16];
//     while (true) {
//         if (uart_read_line(buf, sizeof(buf), 2000)) {
//             if (strcmp(buf, "PING") == 0) {
//                 const char* pong = "PONG\n";
//                 uart_write_bytes(UART_PORT, pong, strlen(pong));
//                 ESP_LOGI(TAG, "UART handshake OK — received PING, sent PONG");
//                 return;
//             } else {
//                 ESP_LOGW(TAG, "UART handshake — ignoring unexpected: \"%s\"", buf);
//             }
//         } else {
//             ESP_LOGI(TAG, "UART handshake — still waiting...");
//         }
//     }
// }
//
// static void uart_echo_test(void)
// {
//     const char* msg = "hello from mcu3";
//     char tx[32];
//     snprintf(tx, sizeof(tx), "%s\n", msg);
//     ESP_LOGI(TAG, "UART echo test — sending: \"%s\"", msg);
//     uart_write_bytes(UART_PORT, tx, strlen(tx));
//     char rx[32];
//     if (uart_read_line(rx, sizeof(rx), UART_ECHO_TIMEOUT_MS)) {
//         if (strcmp(rx, msg) == 0) {
//             ESP_LOGI(TAG, "UART echo OK — received: \"%s\"", rx);
//         } else {
//             ESP_LOGW(TAG, "UART echo MISMATCH — expected: \"%s\" got: \"%s\"", msg, rx);
//         }
//     } else {
//         ESP_LOGW(TAG, "UART echo TIMEOUT — no response within %dms", UART_ECHO_TIMEOUT_MS);
//     }
// }

// ═════════════════════════════════════════════════════════════════════════════
// OLED task — Phase 2.2
// ═════════════════════════════════════════════════════════════════════════════

static void oled_task(void* pvParameters)
{
    OledDisplayWroom* oled = static_cast<OledDisplayWroom*>(pvParameters);
    char line3[24];
    char line4[24];

    ESP_LOGI(TAG, "OLED task started");

    while (true) {
        SharedState snap;
        xSemaphoreTake(gDisplayMutex, portMAX_DELAY);
        snap = gSharedState;
        xSemaphoreGive(gDisplayMutex);

        snprintf(line3, sizeof(line3), "R:%lu W:%lu",
                 (unsigned long)snap.readCount,
                 (unsigned long)snap.writeCount);

        const char* acct = (snap.lastAccount[0] != '\0') ? snap.lastAccount : "--------";
        snprintf(line4, sizeof(line4), "Last: %s", acct);

        oled->showStatus("DATABASE CTRL", "Addr: 0x0A", line3, line4);

        vTaskDelay(pdMS_TO_TICKS(500));
    }
}

// ═════════════════════════════════════════════════════════════════════════════
// app_main
// ═════════════════════════════════════════════════════════════════════════════
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

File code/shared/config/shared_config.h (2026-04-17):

#pragma once

// ─── Shared Inter-MCU I2C Bus ───────────────────────────────
// These pins are identical on all MCUs — hub wiring depends on them.
#define SHARED_SDA_PIN      8
#define SHARED_SCL_PIN      9
#define SHARED_I2C_FREQ     400000  // 400kHz Fast Mode

// ─── MCU I2C Addresses on Shared Bus ────────────────────────
#define ADDR_MASTER_CONSOLE         0x08
#define ADDR_TRANSACTION_PROCESSOR  0x09
#define ADDR_DATABASE_CONTROLLER    0x0A
#define ADDR_JOB_SCHEDULER          0x0B
#define ADDR_IO_CONTROLLER          0x0C

// ─── FreeRTOS Task Stack Sizes ──────────────────────────────
// Units are bytes (ESP32 xTaskCreate takes bytes, not words).
// Sender and logic tasks use ArduinoJson (JsonDocument on stack ~200-300 bytes)
// plus Serial printf — 4096 gives comfortable headroom.
// Receiver and OLED tasks are shallow: semaphore block, memcpy, queue send.
// 2048 is sufficient. Tune with uxTaskGetStackHighWaterMark() if RAM is tight.
#define STACK_SIZE_SENDER    4096
#define STACK_SIZE_RECEIVER  2048
#define STACK_SIZE_LOGIC     4096
#define STACK_SIZE_OLED      2048

// ─── Heartbeat Timing ───────────────────────────────────────
#define HEARTBEAT_INTERVAL_MS       10000   // interval between heartbeat cycles (ms)
#define HEARTBEAT_ACK_TIMEOUT_MS    30000   // slave inactive if no ACK within this window (3× interval)

// ─── Note: OLED pins are NOT defined here ───────────────────
// OLED_SDA_PIN and OLED_SCL_PIN differ per MCU board.
// MCUs #1/#2/#4/#5 (ESP32-C3 SuperMini): GPIO3=SDA, GPIO10=SCL
// MCU #3 (ESP32 DevKit):                 GPIO16=SDA, GPIO17=SCL
// Each MCU defines these in its own config.h.

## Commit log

2026-04-03 task 3 complete: I2C communication verified, PulseView decode captured
2026-04-03 phase 1.5 complete — U8g2 migration and SharedBus implementation
2026-04-04 fritzig diagram not finished
    [bb_full.fzz]
2026-04-06 shared message protocol + api reference
    [bb_full.fzz]
2026-04-17 doc update before mcu3 replacement
    [config.h, shared_config.h]
2026-04-17 mcu3 model name fix
    [bb_full.fzz]
2026-05-09 raspi uart loopback work
